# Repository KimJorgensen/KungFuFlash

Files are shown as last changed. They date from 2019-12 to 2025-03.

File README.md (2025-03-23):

# Kung Fu Flash

Cartridge for the Commodore 64 that packs a punch.

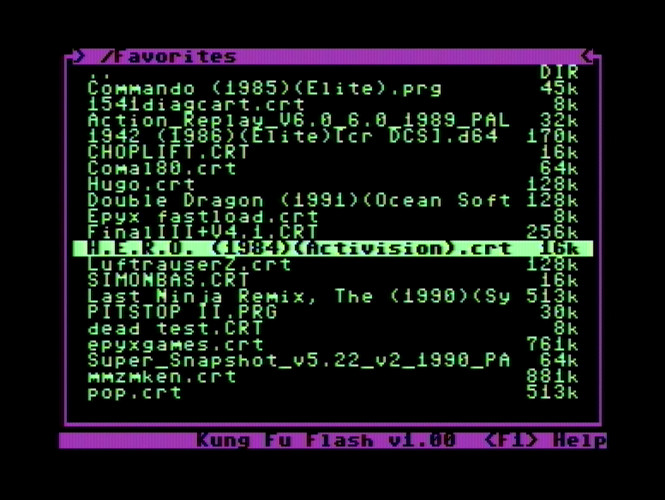
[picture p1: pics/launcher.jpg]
Kung Fu Flash Launcher


Kung Fu Flash can emulate different cartridge types, load PRG files and use D64 disk images.
Just place your desired CRT, PRG or D64 files on a FAT formatted microSD card and use the built-in launcher to execute them.

## Hardware

There are three buttons on the cartridge; a reset button, a menu button for starting the launcher, and a special button that is used by the freezer cartridges.

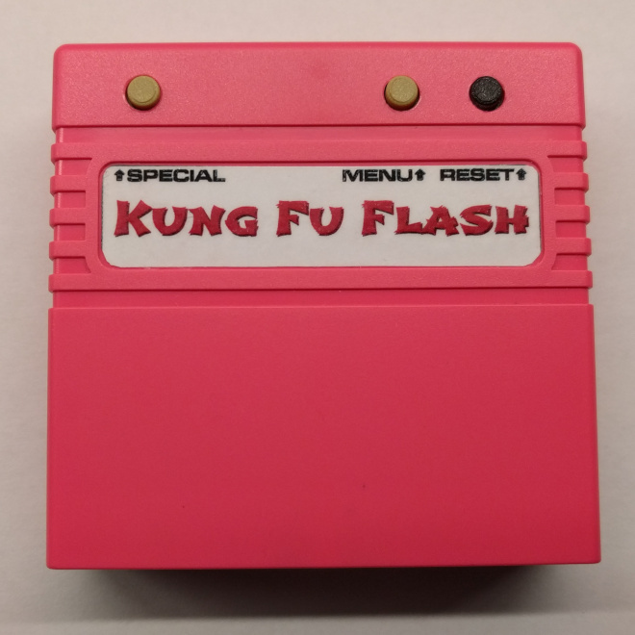
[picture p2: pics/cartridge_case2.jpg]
Cartridge Case


The PCB will fit the Stumpy Cartridge Case from TFW8b, you just need to drill some holes for the buttons and make a cut for the microSD card.
If you have mounted the USB connector you will need to cut a hole for that as well.

You can also 3D print a cartridge case as the one designed by bigby, [see here](https://www.thingiverse.com/thing:4153414).

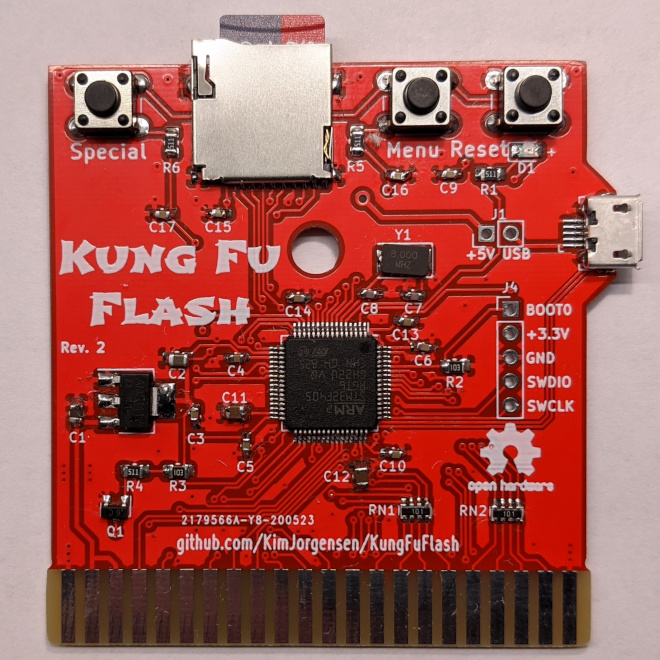
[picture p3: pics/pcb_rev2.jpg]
Kung Fu Flash PCB


The gerber files and BOM can be found [here](https://github.com/KimJorgensen/KungFuFlash/releases/tag/rev.2).

## Supported Cartridges

The following cartridge types are currently supported:

* Generic cartridge (8k, 16k, Ultimax)
* Action Replay v4.x/v5/v6
* KCS Power Cartridge
* Final Cartridge III(+)
* Simons' BASIC
* Fun Play, Power Play
* Super Games
* Ocean type 1
* Epyx Fastload
* C64 Game System, System 3
* WarpSpeed
* Dinamic
* Zaxxon, Super Zaxxon
* Magic Desk, Domark, HES Australia
* Super Snapshot v5
* Comal-80
* Ross
* EasyFlash
* Prophet64
* Freeze Frame
* Freeze Machine
* MACH 5
* Pagefox
* RGCD, Hucky
* Drean
* C128 Generic cartridge (external function ROM)
* WarpSpeed 128

## Supported File Types

The following file types are currently supported:

* Cartridge (CRT)
* C64/C128 generic cartridge (ROM, BIN)
* Disk image (D64, D71, D81)
* Tape image (T64)
* Program (PRG, P00)
* Firmware update (UPD)
* Text document (TXT, NFO, 1ST)

## USB Port

The USB port allows programs or disk images to be transferred from/to a PC using the EasyFlash 3 USB protocol.
The USB port is active when:

* The Kung Fu Flash launcher is running
* A program is started using "Load" in the file options menu (SHIFT+RETURN)
* BASIC is started via F7 in the launcher

Kung Fu Flash shows up as a standard serial port when connected to a PC not requiring any custom drivers to be installed.
This means, however, that the EasyFlash 3 program on the PC side must be modified to support Kung Fu Flash.
For that reason a modified version of [EasyFlash 3 USB Utilities](3rd_party/ef3utils) and [EasyFlash 3 BBS](3rd_party/ef3bbs) has been included in this repository.

## Firmware Update

Just place the KungFuFlash_v1.xx.upd file on the SD card and select the file in the launcher to initiate the firmware update.
The newest firmware can be found [here](https://github.com/KimJorgensen/KungFuFlash/releases/).

For initial firmware installation, [see here](firmware/README.md).

## Limitations

Kung Fu Flash is a so called Software Defined Cartridge where a fast microcontroller emulates cartridge hardware in software.
This makes it extremely flexible, allowing different cartridge types to be supported at a relative low cost.

However, it can be challenging to get the C64 bus timing correct in software and in some places the timing is very close to the limit.
Even though Kung Fu Flash has been tested on different models of the Commodore 64, there is a chance that it doesn't work correctly on your specific model, or requires [phi2 offset adjustment](firmware/README.md#diagnostic).
Use it at your own risk!

Kung Fu Flash will work with the PAL and NTSC version of the Commodore 64 or Commodore 128.

Disk drive emulation is using kernal vectors and will not work with fast loaders or software that uses direct hardware access which a lot of games does.
Currently REL files are not supported and only a subset of the Commodore DOS commands are supported.

## Thanks

Kung Fu Flash was based on or uses other open source projects:

* [EasyFlash 3](https://bitbucket.org/skoe/easyflash) by Thomas Giesel
* [Draco Browser](https://csdb.dk/release/?id=89910) by Sascha Bader
* [fatfs-stm32](https://github.com/colosimo/fatfs-stm32) by Aurelio Colosimo
* [FatFs](http://elm-chan.org/fsw/ff/00index_e.html) by ChaN
* [libusb_stm32](https://github.com/dmitrystu/libusb_stm32) by Dmitry Filimonchuk
* [stm32f4-bare-metal](https://github.com/fcayci/stm32f4-bare-metal) by Furkan Cayci
* [OpenC64Cart](https://github.com/SukkoPera/OpenC64Cart) by Giorgioggì
* [EasyFlash 3 USB Utilities](https://csdb.dk/release/?id=150097) by Tomaz Kac
* [Disk2easyflash](https://csdb.dk/release/?id=150323) by ALeX Kazik

and a few others. Please check the individual files for their license.

Thanks to Bjørn N. Jørgensen for giving this project its name.

Special thanks to the author of [Sidekick64](https://github.com/frntc/Sidekick64) Carsten Dachsbacher for his support and inspiration.

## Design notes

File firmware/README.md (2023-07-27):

# Kung Fu Flash Firmware
The initial firmware installation can be done via the SWD interface (J4) using a ST-Link V2 programmer or via the USB port.
The Kung Fu Flash cartridge should not be connected to the Commodore 64 before this process has been completed.

## SWD (Recommended)
Connect the ST-Link V2 programmer to J4 (3.3V, GND, SWDIO, and SWCLK) and connect BOOT0 to 3.3V.

Rename the `KungFuFlash_v1.xx.upd` file to `KungFuFlash_v1.xx.bin` and use the STM32 ST-LINK Utility from ST to program the firmware.

All wires to J4 should be disconnected once the firmware has been successfully installed.

## USB
Add a jumper to short J1 and a jumper to short BOOT0 and +3.3V on J4. This will power the board from USB and ensure that it is started in DFU mode.

Use the DfuSE software from ST or [dfu-util](http://dfu-util.sourceforge.net/) to install the firmware:

`dfu-util -a 0 -s 0x08000000 -D KungFuFlash_v1.xx.upd`

Both jumpers should be removed after the firmware has been installed.

## Diagnostic
Introduced in firmware v1.27

The diagnostic tool is started by pressing the menu button for 2 seconds (until the LED turns off) and is intended to debug stability problems on some C64 models.
For reference the phi2 clock frequency should be around 985248 Hz for PAL and around 1022727 Hz for NTSC.

As of firmware v1.44, the diagnostic tool allows adjusting a phi2 clock offset to address any stability issues.
Some C64 breadbin/longboards may require a small negative phi2 offset and C64C/shortboards may require a small positive offset.

In the diagnostic tool the following buttons on the cartridge can be used:

* `Special`: Decrease offset
* `Menu`: Increase offset
* `Special`, hold for 2 seconds: Save offset and exit
* `Menu`, hold for 2 seconds: Reset offset (without saving)
* `Special` + `Menu`, hold for 2 seconds: Reset and save offset. This combo will also work without starting the diagnostic tool first
* `Reset`: Exit diagnostic tool without saving offset

The phi2 offset is saved to the KungFuFlash.dat file and is reset if the file is not found on the SD card.

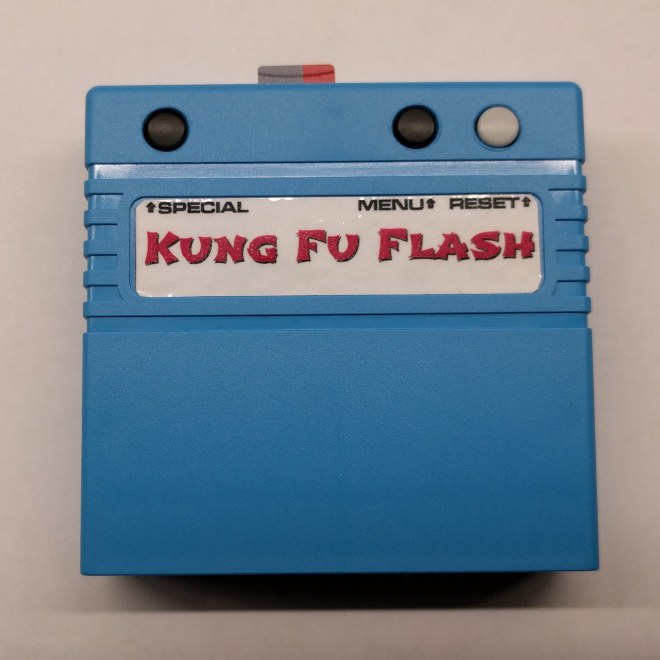
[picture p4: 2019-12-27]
pics/cartridge_case.jpg

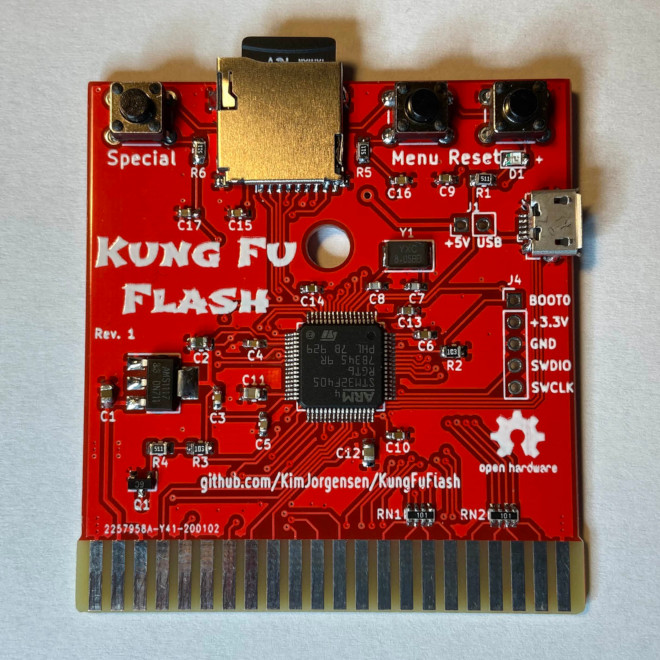
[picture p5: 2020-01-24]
pics/pcb_rev1.jpg

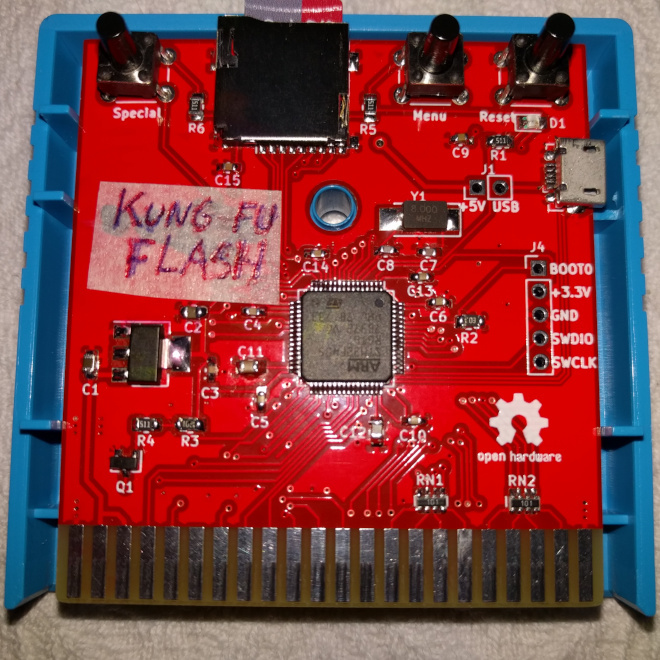
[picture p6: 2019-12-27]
pics/prototype.jpg

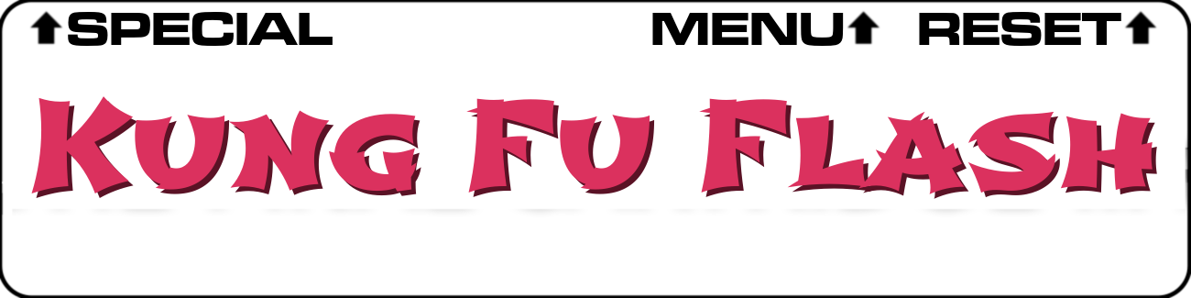
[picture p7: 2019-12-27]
pics/label_600dpi.png

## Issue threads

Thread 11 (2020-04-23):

BOM mistake

djtulan, 2020-04-23:
Hi!
In BOM there is a little mistake.

_Tactile Push Button Micro Switch - Use 6x6x6mm with TFW8b button caps or 6x6x9mm with 3.1mm A101 Plastic Switch Button Caps_

If somebody want to use the A101 Plastic Caps a 6x6mm with 10.5mm - 11mm height ist needed.

KimJorgensen, 2020-04-23:
Thank you for reporting this. That should be fixed.

djtulan, 2020-04-23:
The button height should be exactly 11mm. From the PCB to the top. I measured it again.

KimJorgensen, 2020-04-23:
Thanks. I'll update the BOM with this.

djtulan, 2020-04-23:
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

KimJorgensen, 2020-04-26:
The BOM file has now been updated with the correct size of the push buttons.
Thank you.

Closed 2020-04-26.

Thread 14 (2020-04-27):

Kernal support

dikdom, 2020-04-27:
Hello,
I was checked this cart (fantastic work, btw) and compared with EF3 and I realized that this one doesn't support the KERNAL switch, meaning that you could select a KERNAL image to replace the original one.
Is there any particular reason for that or just simply missed from the initial feature list?
Sorry for my ignorance I don't know how big deal is to implement that, so it may be a noob question..

KimJorgensen, 2020-04-27:
After being asked about this on forum64 I have looked a bit into it, but I think it is good to keep track of the issue here.
I have tried to implement the method described in "[Designing a Real KERNAL Cartridge](https://github.com/KimJorgensen/easyflash/releases/download/EF3-FC3/kernal-cartridge.pdf)" by @skoe but has not been successful so far. Pulling A14 low from KFF does not seem to work, maybe the timing is off or maybe the signal isn’t pulled low enough.
More investigation is needed.

dikdom, 2020-04-27:
Thanks for your reply and thanks for sharing a the doc, I haven't seen it earlier!

In the KFF there is only a 8MHz clock (oh, OK, you may have PLL), on the other hand I don't understand why it doesn't cause any conflict (HW failure in time) to pull down A14 externally while the CPU may drive it to high..
And yes, the doc doesn't mention how does the EF3 pull down the A14 safely (below 0.8V I guess) without burning the CPU.

Thanks for your time!

KimJorgensen, 2020-04-27:
The ARM processor runs at 168MHz but there are delays involved reading the bus, checking for the correct condition, writing back to the bus etc. It will almost always be slower than when implemented in hardware or a CPLD as EF3.
If you check the schematic for EF3 there is no hardware protection on A14. The signal goes straight to the CPLD which can sink up to 70mA if I read the datasheet correctly.
I think the key to not damage the CPU is that A14 is only pulled down a fraction of the clock cycle and this is only done after a write to address $0000 or $0001.

skoe, 2020-04-27:
@KimJorgensen This is correct. These are the points that allow this to be done:

- NMOS pull-ups are quite weak. They can't source much. However, the closer the output comes to 0V, the stronger they get.
- It's a fraction of a clock cycle only, as you said.
- It happens at most every few clock cycles, usually much much more seldom. So the FETs can't heat up.
- Actually, similar effects happen in every machine: When the chip select changes from one IC to another, not all of them have the same speed, so the data bus may be driven from one IC already before the previous IC lets it go.

About the timing: It must be really very accurate I remember. It was many years ago, details I can't remember unfortunately.

Hope this clarifies your question. Note that I didn't have a look at this project but got a notification from github :)

dikdom, 2020-04-28:
Hello,
checking the STM32f405RG spec I read a note (DocID022152 Rev 8, page 59):
"PC13, PC14, PC15 and PI8 are supplied through the power switch. Since the switch only sinks a limited amount of current
(3 mA), the use of GPIOs PC13 to PC15 and PI8 in output mode is limited:
- The speed should not exceed 2 MHz with a maximum load of 30 pF.
- These I/Os must not be used as a current source (e.g. to drive an LED)."

1) Can it be the cause that you cannot change at proper speed the /GAME and /EXROM lines (max 2MHz seems not enough if you need to pull them down for 80ns or 160ns)
2) PC13 is a current sink, so driving a LED is not a problem here, I guess.
3) I have one more question thought it seems trivial (but not for me, sorry). How do you know that the ARM chip is 5V tolerant?

KimJorgensen, 2020-04-28:
@skoe Thank you for taking the time for the clarifications and for your excellent document. If you can find the time, please consider putting the newest version on your website so others can find it too. From what you are saying I assume that the timing is off but I really need to verify that with a logic analyzer.

@dikdom
1. That could be. I haven't really spend any time investigating this
2. Yes, using it as a sink works fine. I'm not sure that is documented anywhere
3. In table 7 in the document that you referenced there is a "FT" next to each pin that is 5V tolerant

It was actually quite a puzzle to map all signals to pins, as they all are in use. Not all are 5V tolerant, some have a different use when running the bootloader which could damage the C64, and not least, it should easy for the software to read the address and data bus without having to do bit shifting.

dikdom, 2020-04-28:
3. I just should have read 2 more lines... :) The note I sent earlier is in the same legend of the table 7 you are referring to..
I can deeply understand the puzzling part. I'm not an expert, designing a PCB for me is let the autorouter do the job (under a few MHz there should not be too much harm)..

So in this case I'll probably wait sometime with the ordering the PCB and I hope you will come up with a good solution... :)
I would multiplex the /EXROM and /GAME with the SD reader pins (you don't use the SD and the C64 at the same time, I assume) and disconnect the C64 lines with a 4066 like switch when using the SD.
But the SD lines are the other side of the MCU and of course I don't know if the multiplexing could be done at all, and the bit-banging... and.. a lot more can be considered I don't even think about.

medzes, 2021-02-01:
HI all,

I've successfully been able to get kernal mode working exactly as skoe documented in his excellent article in KungFuFlash, using the DEVEBOX prototype I have. The tricks needed to do that are primarily a lot of work getting the timing right and checking the oscilloscope.
Now I don't own a regular KungFuFlash cartridge so I cannot test / check the timing for the regular cartridge and I can also not check the slope speeds of the signals for the regular PCB rev2 version. I have PA14, EXROM, GAME on a regular GPIO. (not on PC13,14,15). But I expect the same tricks below would work on PCB rev2 as well.

What was needed to get it to work:
- Normal 5V tolerant use for EXROM, GAME means open-drain config. However, this means both EXROM and GAME have a rising edge slope that is far too slow to reach the timing mentioned in skoe's document during the A14 tests.
- It is also likely in some corner cases like some C64 PCBs or some specific address transitions causing voltage drops, the half-cycle delay between releasing GAME and the begin of next CPU cycle may not allow GAME to be pulled up fast enough by the resistor inside the C64 alone.
-  So, a trick is needed to momentarily set EXROM/GAME to normal high output with a 4 cycle wait (in my tests) to let EXROM/GAME reach 3.3V, before releasing them to let the pullup resistor in the C64 handle the rest.
- We cannot leave EXROM/GAME in output mode all the time as that would mean the C64 pullup resistor for EXROM/GAME will increase the 3V3 on the ARM IC. This may lead (if the arm is not consuming enough power) to a 3V3 above 3.6V, which damages the ARM.
(I have however programmed EXROM/GAME to output fixed by mistake though, and that didn't blow up anything - then again the 2 LEDs on the DEVEBOX alone draw a few mA alone, probably sufficient to keep the 3V3 below 3.6V)
- A14 is pulled low very fast after it is set to output, and rises back high very quick too after release. No special stuff needed.
- The A14 check loop requires more time before the interrupt occurs than the existing cartridge timing allows. I've re-implemented a specific handler from scratch with earlier interrupt timing to fit the tighter timing.
- The A14, EXROM, GAME OTYPER/MODER toggling are highly dependant on exact cycle delay inbetween the actions. Using NOPs didnt allow sufficient time for all functions so I had to move some logic around As a result, the code is C but it is so sensitive to the compiler / optimizer and exact constants, it might as well be assembly.
- The 48kB code size is very full, so I switched to -Os and some always_inlines. This allows the kernal code to fit.

I will upload my changes to my fork after I have been able to run some tests that perform $00 / $01 tests. Does anyone have some suggestions what C64 software to use (that changes $00/$01 a lot and is very sensitive) to test the functionality properly?

skoe, 2021-02-01:
Congratulations :) Regarding the tests: I tested the mechanism with hand written assembly loops, because this made it easy to check everything on a logic analyzer. And when this worked, I run all kinds of programs :)

Did you also implement the mechanism from chapter 2.2 Optimizations to avoid pulling down A14 in every cycle? The will reduce the stress on the bus drivers significantly.

medzes, 2021-02-01:
Hi skoe,

Thanks for that insight. I guess I could also write and use some handcrafted loops, will take some time to integrate that.

Yes, I have also implemented the mechanism to avoid pulling down A14 every cycle as you suggested. In fact there are 3 separate interrupt service routines, currently using a state variable. It could be optimized using 3 separate ISR vectors, that would make the A14-check ISR with its tough timing more compatible with background usb or other activity by switching to the less restrictive timing (without the A14 check) on the fly.

I notice in the idle kernal loop, there are occasional $01 writes happening at some kHz rate. So from this I believe its all working correct. The interrupt timing of the arm is fortunately very exact so far. I may need to support a 1 or 2 cycle ISR delay inaccuracy - I use a C64 VIC cycle alignment style loop to get to 1 cycle accurate timing based on the Timer capture value. That part was very fun - almost exactly like using the 6526 timer to get in lockstep with the VIC, but then on the ARM with phi2.

medzes, 2021-02-11:
Hi, I've been able to find the time to clean up my code,  test it a bit and make it ready for others to check out. You can find the kernal mode on my fork. It can be compiled for PCB rev 2 or DEVEBOX using a define in the Makefile.
This version is not yet rock steady, but it does work for many code and games.
The code supports two mode:
- Select a kernal ROM file. Drops you into a normal basic screen.
- Place a file called "kernal.bin" on your SDcard. If this file is detected, it will be used to start PRG and disk based programs from the easyflash menu.
Please note I have not checked the PCB rev 2 version as I don't own one.
If you are interested to test, please be aware the constants of peripheral base addresses are different which can make the compiler create code with slightly or even big timing differences. It is best to compare the generated kernal_handler code in the build/main.lst by hand in case of doubts.
Also it is a good idea to check with an oscilloscope the timing of the A14 check and the $de02 write check. The kernal.c file contains some notes how you can do that and what timing to expect.

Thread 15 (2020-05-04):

BOM question

dikdom, 2020-05-04:
Hello,
could you please put a photograph about the cart from the USB socket side as I'm having a hard time figuring out what kind of USB socket is needed (tbh I'm afraid of ordering from Ali because of the arrival time of the free shipped orders...). So. On the kicad PCB file it seems that the bottom pin is the pin 1, +5V from USB, top pin is GND, pin 5. So, checking the pinout of the microUSB socket from the wiki (https://en.wikipedia.org/wiki/USB_hardware), the socket has to be laid on its longer side (shorter side of the microUSB trapeze is UP). But checking the picture on the ali link you specified in the BOM, it is quite the opposite. So which one?
I assume you already used the USB interface of KFF, so it works that way you have in your cart.
A picture would help me a lot.
Thanks!

KimJorgensen, 2020-05-04:
Hi,
The bottom pin is pin 1 and the socket is laid on its short side, just like shown on the wiki (https://en.wikipedia.org/wiki/File:USB_Micro-B_receptacle.svg).

Here is a picture:
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
And yes, the USB interface works fine.

Hope this helps and please let me know if you find a suitable replacement.

dikdom, 2020-05-04:
Thanks, then I mixed the front and back view... This picture is not so straightforward.. https://en.wikipedia.org/wiki/USB_hardware#/media/File:USB_2.0_connectors.svg
I'm glad I asked! :)

For the micro USB B socket I hope this will work for me: 10118194-0001LF from Amphenol.
For the micro SD card socket I'm targeting this: 112J-TDAR-R01 from Attend.

Some months and I will let you know the results! :)

Closed 2020-05-04.

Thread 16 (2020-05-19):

troubleshooting

dikdom, 2020-05-19:
Hello,
a little help would be appreciated...

So, PCBs arrived, most of the parts are pre-soldered. USB and SD slots, switches and jumper headers had to be soldered by me - done. Checked the USB slot with a cut USB cable, each wire is OK (+5V, GND, D- and D+, no shorts)

- firmware (v1.08) is uploaded ('Downloaded' in the terminology of dfu-utils) and read back ('Uploaded') and verified. It is OK.

Q1: is it true that the computer should be able to see the board if I press all the three buttons at the same time? I have to press them at once in order win10 be able to see it.

Q2: no LED activity, when the board is connected to USB. Is it normal?

- OK, fw programmed, when I try it with C64, the LED is lit but the screen remains black. With an SD card, without an SD card.

I tested the SD slot's pins and they aren't shorted.

Q3: Any idea where to start the debugging?

UPDATE#1:
A3: RN1 and RN2 is 10k resistor networks. Needs to be replaced, to be continued...

KimJorgensen, 2020-05-21:
Hi,

Q1: There is no functionality that requires you to press all buttons at once. It may be necessary to press the reset button after shorting BOOT0 and +3.3V to make the microcontroller enter the built-in bootloader. When the bootloader is running the device should be detected by windows.

Q2: Yes, there is no LED activity when the bootloader is running.

Q3: If replacing the resistor networks doesn't help then try it with a different C64, preferably one with an original kernal and PLA.

dikdom, 2020-05-21:
Thanks!

rickard-von-essen, 2020-08-11:
@dikdom was this resolved by replacing RN1/RN2?

dikdom, 2020-09-07:
@rickard-von-essen yes, it did the trick.

Closed 2020-05-21.

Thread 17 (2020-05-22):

Questions

dikdom, 2020-05-22:
Hello,
finally I managed to fix my cart and it starts, it works. Most of the things are abvious and fine but I have some questions:
1) when I turn on the cart or reset sometimes it starts with the normal C64 boot screen and sometimes it goes directly to the KFF menu. What does it depends on?
2) I have found the F5 configuration option. What does that exactly mean? Is there any longer description about it somewhere?
3) Final Cart III and FC III+, the freeze menu is strange, though it works. There is some flash on the upper menu and on the drop down menu, but it is responsive to the keys and works. I will attach a screenshot later (motherboard 250407, normal PLA chip). With a FCIII+ cart and with an original FC cart there is no problem on the freeze menu on this machine.
4) What driver shall I install onto windows 10 in order ef3util.exe to work? The driver from the EF3 site cannot be installed as it is not signed.
5) What happens if I happen to turn off the machine while it is loading (flashing?) one of the .crt images - when I select those? Will the KFF be bricked? Or just the Action Replay will not start? Or?

Thanks a lot,
Sandor

dikdom, 2020-05-22:
Let's skip 3) as I have a slightly broken SID chip in this machine. With a different, c64c machine there is no problem with this cart. I have to check different SID also...

KimJorgensen, 2020-05-22:
Hi,
Good to hear that you got it working.

1. That depends on your last selection. Say you select BASIC (F7) then the cartridge starts in BASIC after reset or power on. If you don't wan't the cartridge to "remember" your BASIC selection this can be changed in the settings menu (F5)
2. Sorry, there isn't any longer description. Hopefully it is understandable what is does with my answer to your first question.
3. There are timing differences between different C64 machines and as the timing is close to the limit there is a chance that you encounter a machine where the cartridge doesn't work correctly. If you have the possibility to replace the SID chip let me know if the problem persists.
4. It shouldn't be necessary to install a driver as KFF is added as a COM port but you need the ef3usb.exe from the KungFuFlash GitHub page.
5. There is a slim chance that it will be bricked, but most likely the flash will be corrupted and KFF will start the menu next time it is powered on.

/Kim

dikdom, 2020-05-22:
Thanks!
1) so if I set the config in F5 to 'no' then it will always powers on onto the menu . If I set the config to 'yes' it will powers on into BASIC. The
resets will always takes you to the last selection (prg load, mount, etc..) regardless of the config. Did I get it right?
3) sure I will
4) hm.. I'm using the .exe from your github, so probably yes, it was ef3usb.exe . How long should it take to transfer one .prg file? Minutes? After 30s-60s I stopped the process as it seemed it crashed. Same with the testing. It prints it started but then nothing...

KimJorgensen, 2020-05-23:
1. No. Power up and reset works the same way.
In the default configuration KFF will always take you to the last selection which includes BASIC. If you set the config to 'no' then the BASIC selection wont get saved and KFF will go to whatever you selected prior to BASIC.
4. The transfer should only take a few seconds. What command exactly did you run, and did you make sure to specify the correct COM port?

dikdom, 2020-05-23:
point 1)
now I understand. KFF will always boots up to the latest selected action, the config only selects if these actions would include the BASIC screen or not. Ok, I was completely off the track with this.

point 3)
The working SID didn't solve the problem. In fact, when I started the freezer menu of FCIII on another 250407 board, then the menu line was also corrupt, but not that much, only within one raster line. Starting the KFF in a 425 board, then the freezer menu was OK. I have tested KFF on a 469 also, and there were no problems either.

point 4)
I executed 'mode' command to check the usable COM port. It was COM6 in my case. If I remember correctly it was 'ef3usb.exe com6 test' and 'ef3usb com6 c xy.prg' or something like that. The menu screen changed on the C64 screen, so something had happened, but not quite what I expected..
I will try different C64 machines.

Good news is that I managed to test with the PLA20V8 PLA replacement and it works with it as with the original PLA.

KimJorgensen, 2020-05-23:
3) Thank you for testing this. I'll try to see if I can fix that once I got my 250407 board working, but it is quite tricky to get the timing right so that it works across all board revisions.
4) Just like EF3 you must send the ef3usb.prg program to the C64 first before you can use the test or copy command. So try to execute `ef3usb com6 s` first

Thank you for the info about the PLA. I'll update issue #12 with this.

dikdom, 2020-05-23:
4 - ef3usb.exe works as you described. I don't have an EF3 so I was not familiar with the procedure. And I stopped reading the doc at: 'PC has installed Easyflash 3 USB driver.' (quite the beginning of the readme.txt)
A small disappointment that this utility is not for transferring data to SD card, and quite a pleasant surprise that it is possible to transfer image/files onto real 1541 floppy disks.
Thanks for your support!

KimJorgensen, 2020-05-24:
Yes, the readme file should be updated.
The only change that was made to EasyFlash 3 USB Utilities was the how it communicates with the cartridge. No features were added to read or write to the SD card.

I don't think I would extend this utility with these features but rather have it build into the Launcher (see #13)

dikdom, 2020-05-24:
Ok, thanks!

Closed 2020-05-24.

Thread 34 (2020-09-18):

DFU Mode

Icelvlan88, 2020-09-18:
Hello,

I cannot get my unit to go into DFU mode. I checked all my connections and I just can't get it to go. I shorted J1 and BOOT0 to 3.3v.

I also checked continuity between my usb pins and the processor. I'm not getting any voltage. I also tried using a different USB cable and no go. I tried both applications you suggested swell.

Can you give me any ideas on what I should be trying? Is there something that is supposed to be sitting between the usb cable and the PC? Using windows.

C-64Bram, 2020-09-18:
I had the same problem. After rebooting my pc the card became visible in DFU mode. It the device is removed and reconnected ,  it sometimes becomes visible again and sometimes I have to reboot again.

jgilcas, 2020-09-18:
Same issue here, i bought a stvlink programmer and everything works perfectly, for 2e i dont expend time to solder jumpers pins

C-64Bram, 2020-09-18:
Like this?

https://www.st.com/en/development-tools/st-link-v2.html

Op vr 18 sep. 2020 13:09 schreef jgilcas <notifications@github.com>:

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

jgilcas, 2020-09-18:
This one: https://es.aliexpress.com/item/32719963657.html?spm=a2g0s.9042311.0.0.274263c07ACJ8a

C-64Bram, 2020-09-18:
Nice. :-)
Just ordered one. :-)

Op vr 18 sep. 2020 14:45 schreef jgilcas <notifications@github.com>:

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

Icelvlan88, 2020-09-18:
I ordered one from a different vendor and receive a STC Auto Programmer USB-TTL. Will this function? Pins looks to have different names

On Sep 18, 2020, at 8:49 AM, C-64Bram <notifications@github.com> wrote:

Nice. :-)
Just ordered one. :-)

Op vr 18 sep. 2020 14:45 schreef jgilcas <notifications@github.com>:

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

—
You are receiving this because you authored the thread.
Reply to this email directly, view it on GitHub<https://github.com/KimJorgensen/KungFuFlash/issues/34#issuecomment-694847699>, or unsubscribe<https://github.com/notifications/unsubscribe-auth/APCADXLSNNZLJFJTI52WDWTSGNJOLANCNFSM4RRNSAHQ>.

dikdom, 2020-09-24:
Hello,
check, if you have 5V between the J1 pin header (if it is shorted then any of its pins) and ground (shield of USB). If you have 5V check the voltage regulator whether you have the 3.3V at its output. If you have it, you should check the MCU also to have the 3.3V . Make sure the two pins of J1 and 3.3V and BOOT0 pins on J4 are shorted.
After connected everything, press the reset button of the card, it helped to be identifiable by my PC.
I used dfu-utils and the latest .upd binary to flash my card. It worked for me.

Closed 2024-12-29.

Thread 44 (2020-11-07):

STM32 Program

Icelvlan88, 2020-11-07:
Hello,

I'm trying to program the STM32 and I keep getting an error. "Connect Under Reset" mode Target -> Settings menu and try again.

I tried programming another STM32 and was able to, so I know my usb is working correctly.

Can you tell me which pins should be connected directly to Boot0, 3.3V, GND, SWDIO, SWCLK and ill try to connect directly to the processor?

I have pin 1 on the STM32 facing C13, so I know the orientation is correct.

I also tried to reflow the board with no luck.

Also, if D1 is not on the board will it still function to program?

KimJorgensen, 2020-11-07:
Hi

Are you using a ST-Link v2? If you got the microcontroller from China there is a chance that the read out protection is enabled. In that case you need a ST-Link v2 and the ST-Link Utility from ST to unlock it.

The schematic for Kung Fu Flash can be found [here](https://github.com/KimJorgensen/KungFuFlash/blob/master/hardware/KungFuFlash.pdf) but it shouldn't make any difference if you connect the pins directly to the microcontroller. D1 is not needed for programming the board.

Icelvlan88, 2020-11-07:
Hello,

I got a ST-Link v2 and the microcontroller is not from China. What is the process to unlock incase? I checked all my continuity and everything looks fine. It says Detection fail on the STM32 settings in the ST-Link utility.

Can you confirm pin 1 on the STM is the corner where C13 is located?

KimJorgensen, 2020-11-07:
The ST-Link Utility will detect if the read out protection is enabled when you try to program the microcontroller and give you the option to unlock.
The microcontroller needs 3.3V which it should get from the ST-Link v2 and the BOOT0 pin should be connected to 3.3V. I guess you have done that, so I would recommend checking the solder joints on the microcontroller with a microscope if you haven't already.

Yes, pin 1 is in the corner where C13 is located. You can see the orientation of the microcontroller [here](https://github.com/KimJorgensen/KungFuFlash/blob/master/pics/pcb_rev1.jpg)

Icelvlan88, 2020-11-07:
For the programming portion, does any other pin need and or 3.3v?

KimJorgensen, 2020-11-07:
You only need to connect 3.3V to to the J4 pins labeled "+3.3V" and "BOOT0".

Icelvlan88, 2020-11-12:
I soldered 3.3V and BOOT0 together. Might have a bad chip. Ordered a new one.

Icelvlan88, 2020-12-13:
Was able to program, but I have an NTSC C64. Any idea when you'll be able to add support? Is it a software or hardware thing? When the cart is inserted, the system won't turn on.

KimJorgensen, 2020-12-14:
NTSC support is a software issue that is being worked on. There is already an issue for this (see #6) so I'll close this one.

Closed 2020-12-14.

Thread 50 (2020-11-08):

D64 with loading in game not working

Outrun69, 2020-11-08:
When I load a game in which there are other loads, such as the title screen and then the following levels, it does not work.  In-game loading does not work.
Another exemple : I load koala painter and when I want to load picture there is an error message : device not present.

mrr19121970, 2021-01-21:
Is it possible to respond to the mw and me commands the same as an sd2iec ? For example in fload https://csdb.dk/release/?id=114912 if the response is the same as sd2iec then the fast load is disabled and kernel routines are used instead

medzes, 2021-05-01:
Hi, I think this could be reconsidered.

I've done some analysis on the delta between the set of working SD2IEC images and the working KungFuFlash D64/ D81 images.

Surprisingly only few of the SD2IEC D64/D81 images seem to use a fastloader. Most of them use a regular kernal fallback.

I estimate on top of the current working KungFuFlash set, around 400-800 existing SD2IEC D64/D81 images could work out of the box if the CBM-DOS command set is extended to a more complete set.
I checked using Vice's +virtualdevice mode. In that mode, a virtual drive is connected where most CBM-DOS commands work but all the memory-read, memory-write and memory/block execute commands generate a "Syntax Error".
Supporting (most) of the virtualdevice CBM-DOS commands seems to be enough to make the fastloaders in the SD2IEC set disable themselves, and supporting the track/sector loading/saving (U1/U2) as well as opening files with CBM-DOS extended naming like "0:A4,S,R" seems to be sufficient, use character-by-character mode for both read and write.

Supporting these D64 images, does require some refactoring of the current D64 support code on both C64 and ARM, then after that refactoring some implementation of the basic CBM-DOS command set.

- One more Kernal call (CHROUT) needs to be trampolined. This might be done if the filename buffer at $df00 currently is removed and replaced with character-by-character calls.
- Parsing commands on channel 15, and extended filename support on other channels.
- The Open and Close could be done using only Talk/Untalk Listen/Unlisten like the actual device does
- Supporting the 15 buffers fully
- REL file support (although I don't expect that to be used much in the SD2IEC set)

Most of this is quite doable, but I do wonder if the added ARM code would still fit in the available space. I expect the ARM code would take > 8 kB of space at least.

findrepo, 2022-04-05:
Dear contributors,

I just started using this cartridge recently and I mostly use D64 files, but with mutliple disk games.

It is an issue even for PC/Android etc emulators that when I select an other disk it interrupts the current running code or resets and executes/types in the LOAD command etc.

All I want is just to be able to mount a different D64 image without interrupting the current game when it asked me to change the disk in the drive.

I think with the current implementation here, I have to push menu button which makes a RESET and runs code from FW and I can mount other disk, but the running game already wiped out...

There could be an easy solution for it I assume:

- selecting a D64 would set the file path/name in a variable of the MCU, so just some local variable not in the C64 loader program like "idoregesz_disk1.d64"
- when pushing the "special button" the MCU could increase a counter like "idoregesz_disk2.d64" in the file name and mount the disk with the incremented name and call the routine on drive as tray open and closed/ejected disk and inserted (if possible)
- game would not be interrupted as everything happens in the MCU level...

I know it won't be a perfect implementation as need to put images in a sequence but could be a workaround for change the disk ingame issue.

What do you think?

If possible I can also help in the implementation and fork and try to implement is, just might need some advices where to start as I have limited time developing hobby stuff :(
I worked in STM32 based projects, mostly on drone firmware modifications previously.

CqaZ80, 2022-08-01:
> Is it possible to respond to the mw and me commands the same as an sd2iec ? For example in fload https://csdb.dk/release/?id=114912 if the response is the same as sd2iec then the fast load is disabled and kernel routines are used instead

I think KIM did not see this message, maybe he missed it, you could publish it as a new topic.  I think your proposal is very good!!!  that would improve compatibility a lot!!!  and many D64 images that don't work today could eventually work.

Closed 2024-12-29.

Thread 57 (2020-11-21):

KFF rev 2 pcb black screen issue

tdididit, 2020-11-21:
Hi,

I have a black screen issue.
I've been trying two firmwares 1.09 & 1.14 with same result on 2 assembled boards

Firmware flashed with ST-LINK v2.
Device is entering into DFU mode too, without BOOT0 jumper windows is detecting it as a Kung Fu Flash.
Because i have in one of my C64 swinSID (it beeps on reset) I know that system is resetting after RESET & MENU button press.
LED on KFF is lid

tdididit, 2020-11-21:
SOLVED

I replaced Q1 transistor with 2SC945 and it works now :)

Closed 2020-11-21.

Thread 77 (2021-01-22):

New PCB revision for backwards pointing buttons ?

UffeJakobsen, 2021-01-22:
First KFF is becoming a really nice project :-)

I've on several occasions experienced that pressing the cartridge buttons tend to "wriggle" the cartridge in a way that the system crashes (freezes).

A qualified guess is that the "wriggle" happens due to the upward pointing location of the buttons.
If the buttons were backwards pointing this would not happen.

This is observed from time to time with two KFF carts in four different systems - and I must admit that it is annoying that the user has to be careful about how he/she presses the buttons and/or need to support the cartridge with standoffs on the backside.

I know that the backwards pointing buttons has another mounting-layout - so my suggestion would be to incorporate this into any planed revision of the PCB.

KimJorgensen, 2021-01-25:
I have experienced the same thing on one of my boards but cleaning the connector did resolve the problem. So I'm wondering how many has this problem and if cleaning the connector would also help them?

uffejakobsen, 2021-01-25:
> I have experienced the same thing on one of my boards but cleaning the connector did resolve the problem.
> So I'm wondering how many has this problem and if cleaning the connector would also help them?

Well, I have tried that also - but I still see crashes caused by pressing the buttins from time to time...
I guess that our C64's are just getting old (they are) and the expansion port have been in used and worn for over 35 years.
Most other cartridges have backwards pointing buttons - and they do not give me the same trouble when used with the same boards

rickard-von-essen, 2021-01-25:
A device like this is helpful:

https://www.ebay.com/itm/Tombstone-64-Commodore-64-reset-board-and-expansion-port-angle-adapter-combo-/283816694848

uffejakobsen, 2021-01-25:
> A device like this is helpful:
>
> https://www.ebay.com/itm/Tombstone-64-Commodore-64-reset-board-and-expansion-port-angle-adapter-combo-/283816694848

Thanks - but I already own several C64 expansion port extenders :-)

That will only move the problem - you are still pressing the buttons in the wrong direction

Also using an expansion port extender in order to fix this issue seems a little weird...
And it won't certainly help to the success of this device - if a subset of the users will have to apply such "patches" to KFF in order to get stable operation - that should come from the device itself.

pmandes, 2021-03-20:
Hi,
I cloned the main repo and made a separate branch with a new PCB that has right angle tactile switches:

https://github.com/pmandes/KungFuFlash/tree/long-board-cart

...still a work in progress, but I'm almost at the finish :)

kroesi, 2022-02-12:
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

Hello @pmandes,
thank you for creating this fork. Did you build it? Does it work?
I just wanted to order it at jlcpcb with assembly, but the STM32 was to expensive for me at the moment without knowing if it will work.
Krösi

pmandes, 2022-02-12:
Yes I built it, tested it and it works very well, however I didn't make the SMT assembly files so you have to either assemble yourself or generate these files yourself with KiCad.

Closed 2025-03-08.

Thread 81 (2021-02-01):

Unstable sdcard reads

medzes, 2021-02-01:
Hi all,

I have a situation that my sd-card is frequently (25% of the time) mis-read and gives read errors at random times, like when loading the next page of directory entries. Anyone have an idea if there is some timing related issue or some STM32-configuration related setting in the code I could try to change to see if that helps?

KimJorgensen, 2021-02-02:
Based on what you have written elsewhere I'm assuming that you not are seeing these issues with the Kung Fu Flash firmware but are using some derived firmware that you developed.

If you have changed the firmware in such way that you are spending more time on interrupts then you could get timeouts or buffer overruns when reading or especially writing data to the SD card. You could try enabling error logging in diskio.c

medzes, 2021-02-24:
I have finally been able to spend time tracking down the reason for the sdcard issues I was having. Fortunately I've been able to solve them and make KFF work rock solid.

I enable the hardware flow control bit in the SDIO peripheral's control register. After this, I have not had trouble with buffer underruns anymore.
I also implemented support for the 1/4 fifo full bit in the  SDIO->STA status register. When that is high an do 8 fifo reads at once without checking status again.
I also added some __DMB()'s after SDIO register writes, to help lower interrupt lacency.

My main guess why I'm having more issues, where all I changed in KFF is the GPIO ports used, is that the compiler version just happens to have small difference that can have nasty side effects on interrupt latency jitter. Minute code changes to the interrupt routine can cause the C optimizer to take a slightly different path, with a (comparitivly) huge delta in interrupt routine delay. (like needing one more register on stack, or no stack at all, or having a constant as a LDR or as a MOV)

It turns out after measuring that the worst case C64 interrupt delays all happen during a read of the SDIO->STA register. Reading this register takes 7 or 8 cycles (not documented anywhere but I measured this with the debug cycle counter).
But the jitter I measured in the interrupt can be more than just those 7 cycles, if the ARM's write-buffer is still not empty. So the worst-case latency that came up in my measurement, was the SDIO register write (takes around 6 cycles) followed by branch to a load of the SDIO->STA register (7 cycles). Total latency around 15 extra cycles on top of the minimum 12.

It seems due to the non-empty write buffer, but the LDR already being in the pipeline of the ARM, the whole chain cannot be aborted to handle the interrupt any earlier.

@Kim would you be interested in a pull request for the sdio fixes I made?

KimJorgensen, 2021-02-25:
Thank you for your detailed description.

No offense, but to avoid confusion and respect the license, I would appreciate if you distinguishes between Kung Fu Flash and your derived work. As far as I know, Kung Fu Flash does not have any stability problems when accessing the SD card.

It was a conscious decision not to enable SDIO HW flow control due to the problem described in the [errata sheet](https://www.st.com/resource/en/errata_sheet/dm00037591-stm32f405407xx-and-stm32f415417xx-device-limitations-stmicroelectronics.pdf), see section 2.13.1.

I would be a bit reluctant to accept a pull request that fixes a non-problem, especially with the above in mind, but thank you for the offer.

medzes, 2021-02-25:
Ah thanks, I had not seen that errata sheet. In that case the hardware flow control should be left disabled. The 1/4 fifo trick still helps sufficiently for my code.

Agreed, if the SDIO issues are a unique result of the set of pin assignments I am using and possibly different gcc version (I use the one from ubuntu 20) that is fairly strange but no need to merge.

No offence, but I am not sure how to work along with your request on license. I don't think I have sufficient understanding of legal issues to understand the request you have.

I would not expect the changes I made that I have published so far to be allowed to be called a different project. The only substantial change is in one file (c64_interface.c) to allow two optional choices of GPIO pin assignments during compilation and other minor changes to allow -Os compilation. I've personally only seen this as minor software changes to allow support for a "hardware prototype" version of KungFuFlash.

It appears you have far more experience with that than I have, would you care to offer a suggestion how to proceed?

The other changes so far are adding soft-kernal support, optional LCD, and optional side-load of ARM code. Those features use some additional files which I have used the same copyright as yours, but with my name as author. I suppose including those in a compiled binary could be called a derived work, indeed. Would you be happy if I called that KungFuFlash-devebox, to clarifify it works on the devebox prototype ?

KimJorgensen, 2021-02-26:
As long as it is clear that your work is not the original Kung Fu Flash I'm happy.
I'll close this issue and thank you for the info.

Closed 2021-02-26.

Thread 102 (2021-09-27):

Unstable clock values with Diagnostic feature on 1.27

lordoftears, 2021-09-27:
My KungFuFlash works with every C64 I have, but I have a curious issue with my Sixty Clone (assy 250466): often (3 on 5 attempts), when I press the Menu button, I have garbage on screen. Then I press it again and everything is fine. Games are loaded fine and I can enjoy the cart.

I performed the Diagnostic due to the new 1.27 firmware. With the Sixty Clone the clock is moving from 887450 to 987750, while it is ok (fixed value) on a breadbin C64 I tested.
I have no other issues with the Sixty Clone, which is usually connected to a Ultimate 2+ device and has a good video on my 1084s monitor.

KimJorgensen, 2021-09-27:
Is the clock always unstable when you enter the diagnostic? and does it get stable after running the diagnostic for a while?

What chips have you used to assemble the Sixty Clone board? Are they all original Commodore, or has some replacement chips been used?

lordoftears, 2021-09-27:
The clock is always unstable. At each cycle, it changes, I waited for several cycles but it continues moving. It looks strange because with that oscillation the video output should be bad, instead it is good.

The Sixty Clone has original chips except for the PLA and an ARMSID.
Some months ago, when I experienced the issue with the menu button, I tried swapping the chips with a different C64, which mounts original chips, but nothing changed.

KimJorgensen, 2021-09-27:
Yes, I would also expect the video output to be affected if the frequency did change that much. Maybe it is a bad connection on the expansion port?
Have you tried to measure the PHI2 signal with a logic analyzer or oscilloscope?

lordoftears, 2021-09-27:
Unfortunately, I do not have a logic analyzer or oscilloscope, sorry, I cannot be useful in this.
When I encountered the problem at the beginning, I checked with the tester all the connections of the expansion port. The voltage is correct, also other paths seem to be ok. The Ultimate-2+ cart works well, as well as "normal" cartridges.
Also the KFF works, I just have this issue when pressing the menu button, not each time, but often. I also checked the KFF with other computer, it works fine.

ogg1e, 2021-09-27:
I was seeing the same issue on my c64c.  I think it's the expansion port, really. Pushing down on those buttons moves the cart enough to cause things to go bad.   Either we need a new case design so that it has legs that allow the cart to rest on the desk to take the pressure off the port, or KFF needs to have the buttons moved to the backside instead of the top.

KimJorgensen, 2021-09-27:
@lordoftears I don't know about the Ultimate-2+ but most "normal" cartridges do not use the PHI2 signal. It is hard to get to the bottom of this without the ability to measure the signal.

@ogg1e That could explain a problem with the menu button but hardly why the frequency would be unstable when not touching the cartridge.

lordoftears, 2021-09-28:
This evening (CEST Time) I will try on an original C64c, both the menu button that the clock issue.

lordoftears, 2021-09-28:
As I supposed, it works like a charm on my C64c. Frequency fixed at 985214, no menu button issue.

KimJorgensen, 2021-09-28:
@lordoftears Great that it worked on your C64C. Did you use the same power supply for these tests?

Just for info; some have problems with the C64C (see https://github.com/KimJorgensen/KungFuFlash/issues/89) while others have problems with the expansion port connection when pushing the buttons as @ogg1e wrote (see https://github.com/KimJorgensen/KungFuFlash/issues/77)

lordoftears, 2021-09-29:
@KimJorgensen, thank you for the infos. I've used an angled adaptor for the expansion port, because at the beginning I thought it could be the problem. I am following also the other threads.
The PSU are different: a Keelog for the Sixty Clone and an old one of a C64c for the other original C64s (the breadbin and the C64c).

I must try with the same PSU. Anyway, the button menu issue on the Sixty Clone was experienced also with the other PSU.

KimJorgensen, 2021-09-29:
@lordoftears OK, thanks for info.
Regarding the PSU, I was trying to guess why the measured frequency would be wrong and was speculating if that due to noise on the clock signal coming from the power supply. But since you already tried another PSU with the Sixty Clone it can't be that.

However, looking at the service manual for the C64 I can see that the 5V supply for the clock circuit actually is regulated by VR2 on the main board. Do you have a regular 7805 installed as VR2 on the Sixty Clone or are you using some replacement?

lordoftears, 2021-09-29:
I tried anyway with the other PSU, same result.
I made a video about the clock diagnostic to show you the "oscillation". [https://we.tl/t-5slW4hTJW0]

I used a regular 7805 (I took the parts kit from Run Stop Re-Store as I think most of the people having built a SixtyClone).
[https://www.dropbox.com/s/1mjhd0qh7wdb46t/IMG_20210601_222406154_HDR.jpg?dl=0](url)

KimJorgensen, 2021-09-29:
Thank you for the video and picture.
When I read that the frequency was moving between 887450 to 987750 Hz it sounded much more dramatic than shown in the video, where the frequency was moving between 989076 and 989219 Hz.

This had me wondering if this oscillation just is a artifact of the clock circuit being misaligned. Do you know if the clock frequency was adjusted after the board was assembled?

lordoftears, 2021-09-29:
@KimJorgensen I am really sorry, I mistyped the first digit of course... 😕

When I assembled the board, I had black and white image on my 1084s, I adjusted a bit the trimmer and it displayed correctly.

KimJorgensen, 2021-09-29:
@lordoftears Don't worry about it :)

I don't know how accurate the frequency needs to be for the 1084, so I'm not sure what that implies.
Unless somebody else has some insights, I don't think we can get bottom of this unless you somehow measure the Phi2 signal to tell if the frequency is indeed unstable or if KFF has trouble detecting the signal.

lordoftears, 2021-09-29:
I have a multimeter capable of measuring clocks, but I don't think it is accurate at the precision needed. Unfortunately, I cannot afford  an oscilloscope at the moment, I mostly a game player, but if I can find some friend here having that I'll check it. Anyway, I'll try with the multimeter in any case. Apart from this issue on this specific computer, the KFF is something incredible for a game player like me.

KimJorgensen, 2021-09-29:
Glad that you like it.
If there is a bug I'll be happy to fix it, but unfortunately it is really hard to do remote debugging

lordoftears, 2021-10-04:
>
>
> Glad that you like it. If there is a bug I'll be happy to fix it, but unfortunately it is really hard to do remote debugging

I know, I hope to be helpful soon, I think everybody here appreciates the great work you did.

lordoftears, 2021-11-15:
@KimJorgensen I was able to perform some tests:

- replacing the new PLA with an original one, I have the same issue
- with the new firmware, it moves a bit in the rage of 986000Hz and 986200Hz or something like that. Less than before.
- Unfortunately I don't have a sharper tool with more digits, but the clock measured with my multimeter is fixed at 985. 2 MHz

Gabeki17, 2021-11-26:
Hi,

I have one device where the clock is 985119. And it is terrible.

There is a game that might be is the best to test it out.
It is Jupiter lander CRT version.

It is not only sparkling, but the sparkles are even coliding with the lander. :)
Also it goes even worst if warming up. So you die almost instantly.

Is Kungfu checks clock regularly so it can autotune it? Or only on bo

https://user-images.githubusercontent.com/4869862/143604921-fdae42e6-afe1-4e9f-be6c-f4fe75c9995c.mp4

oting?

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

KimJorgensen, 2021-11-28:
@Gabeki17 You could try adjusting the frequency to around 985248 Hz but I doubt this will do much difference. As I already told you in #94; It is probably the KFF that can't meet the timing requirements of the VIC-II on your specific C64.

You could try Jupiter Lander V2 in [this release](https://csdb.dk/release/?id=210760) and see if it works any better. If it does, maybe I can improve the Ultimax mode for normal cartridges as I did for Easyflash. Remember to start the EF cartridge in VIC-II/C128 mode via shift+return.

I would like to keep each issue to one topic so if your clock values is not unstable please keep the discussion to #94

gletonai, 2021-11-29:
My issues on ALDI C64 stopped manifesting with 1.29p, god job.

Gabeki17, 2021-11-30:
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

Thx!,

It also effects other games, like Prince of Persia. (Actually I bought KFF because of. :( )

I would try to tune it, but can't compile the code.
If you can help me with that I could try to solve my own issue, and when it works I can simply give you the information about.

I know there are many C64 behaving a litlle different.

Thank you in advance!

With regards,
Gábor

KimJorgensen, 2024-12-29:
I assume that the original issue was due to a timing problem that can be fixed by adjusting the phi2 offset. Otherwise feel free to create a new issue

Closed 2024-12-29.

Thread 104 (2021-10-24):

Bricked device with firmware update

pff729, 2021-10-24:
I successfully bricked my KungFuFlash.
I tried to update the firmware from 1.23 to 1.27 (both PAL versions). I've updated the firmware before and it went flawlessly: finished in a couple of seconds. But now, I've connected my KungFuFlash to my C64, opened the update file from the microSD, it wrote "updating in progress" to the screen but then nothing happened. I waited 45 minutes, still nothing, so I powered it off. Now, if I plug it into my C64, there is no sign of life: the screen is black and flickering.
I'm not sure what caused this. The difference between versions was too big?
Can it be fixed somehow? Maybe writing a firmware on it through the usb port? Or desoldering and swapping some parts? Or is it bricked forever?

KimJorgensen, 2021-10-30:
Interesting. Now I’m pretty sure that the issue is caused by the changes to the detection of C64 clock signal. If the clock frequency is just outside the accepted range then the KFF will refuse to start but the LED would not blink rapidly.

Here is a new test firmware where two changes has been made:
1. The LED would always blink rapidly if the KFF refuses to start due the C64 clock frequency being out of range
2. The accepted frequency range has been extended a bit

@mofjel Could you try with this new firmware and  report back? Regardless if it works or not, it would be useful to know what frequency you got in the diagnostic tool (pressing the menu button for 2 seconds using v1.27 or the new firmware if it works)

[KungFuFlash_vTST4.zip](https://github.com/KimJorgensen/KungFuFlash/files/7446229/KungFuFlash_vTST4.zip)

mofjel, 2021-10-30:
I have tested the test firmware, and it works!
So I played around with it, using the final cartridge 3 and action replay 6. Ran some games and demos. Everything works as they should as far as I know. And special button as well.
Ran som cartridge games, and they also worked as they should.

I tried the 2 sec menu button press. The frequency did vary a bit for each time I used it.
Highest frequency was 985216Hz
Lowest frequency was 985190Hz
(I did it 3 times)

I did the update using my C64.
I can't find any issues with it using the test firmware, it just works.
I will play around with it some more, and if I notice something, I will report back.
But it's looking good.

KimJorgensen, 2021-10-30:
@mofjel That is good news, thanks for testing.
It seems that the issue was caused by a slightly unstable clock frequency in your C64 and a too restrictive frequency check in the KFF firmware.

If you think it is fun to do experiments, you could try to adjust the frequency closer to 985248 Hz and see if the frequency gets more stable. You would do that with R27 next to the VIC-II chip on a 250407 board.
Just note that the KFF is not a precision instrument, so the frequency reading is not 100% accurate, and if you get the frequency wrong you may lose color on your monitor.

I'll create a new v1.29 firmware release with the changes from vTST4.

KimJorgensen, 2021-10-30:
A [new firmware](https://github.com/KimJorgensen/KungFuFlash/releases/tag/v1.29) has been release that fixes the problem reported by @mofjel

@pff729 I'm not sure if the issue you reported with v1.27 is related to the clock frequency detection. But if it is, and you have access to another C64 then you could try your bricked KFF with that.

pff729, 2021-10-30:
Thanks everyone for the help, I'm currently waiting for my ST-Link V2 programmer to arrive and hopefully I can unbrick my device as well.

mofjel, 2021-10-30:
@KimJorgensen I just want to thank you for taking the time and effort to solve this. And also, it was very fun to participate in this. And if you need help to test anything at a later time, just let me know. I will do it.
I have tweaked the frequency some, so it is closer to 985248 Hz.

@pff729 If you want to try the USB method, I have made a little step by step guide how to do this [here](https://everythingc64.boards.net/thread/1326/kung-fu-flash-usb-flashing)
All the information about how to do it, is out there. But I found it a bit hard to piece it all together. So I just wrote it down so maybe it can help someone.

Sebby75, 2021-10-31:
@mofjel
> I have made a little step by step guide how to do this

Thanks for this... Saved your guide and all tools needed to my KFF microsd card just in case, hopefully I will never need it.

Regards
Sebby75

pff729, 2021-12-20:
Thanks everyone for your help! I managed to unbrick my device with the USB method, installed version 1.32, it works flawlessly. Thanks @mofjel for your detailed guide for the usb method, it is really handy!

csico81, 2023-02-03:
> @KimJorgensen I just want to thank you for taking the time and effort to solve this. And also, it was very fun to participate in this. And if you need help to test anything at a later time, just let me know. I will do it. I have tweaked the frequency some, so it is closer to 985248 Hz.
>
> @pff729 If you want to try the USB method, I have made a little step by step guide how to do this [here](https://everythingc64.boards.net/thread/1326/kung-fu-flash-usb-flashing) All the information about how to do it, is out there. But I found it a bit hard to piece it all together. So I just wrote it down so maybe it can help someone.

Hi @mofjel
Do you still have your guide somehwere? The link does not work anymore. I am facing a similar issue that you had with the Kung Fu flash cartridge. I would take a look at your guide if is possible.
Thank you in advance,
csico

Shadowtrance, 2023-02-03:
> Hi @mofjel Do you still have your guide somehwere? The link does not work anymore. I am facing a similar issue that you had with the Kung Fu flash cartridge. I would take a look at your guide if is possible. Thank you in advance, csico

Salvaged via wayback machine (and corrected so links actually go somewhere).

------
1. Bridge the connection on J1 (+5v and USB) and bridge BOOTO and +3.3v on J4. Use a jumper to bridge this, because you need a way to remove the bridge after you are done. But you could solder in a jumper lead if you want.

2. Download DFU-UTIL http://dfu-util.sourceforge.net/releases/. It is called dfu-util-0.11.tar.gz.

3. You need to uncompress it twice using winzip. You should get a folder called dfu-util-0.11-binaries. You could rename the folder to something easier like DFU or something. Copy the folder to somewhere easy to find it. Like i.e C: or the root of some other HDD. Also copy the version of KungFuFlash firmware you want, into the Win64 or Win32 folder inside the DFU folder.

4. Go to Zadig https://zadig.akeo.ie/ and download the software there. Run it, and it will install the proper USB drivers for this to work. (At least it did for me) You might have to plug in the KungFuFlash for this.

5. Press WIN+R and type cmd in the window. Press enter and the command prompt should pop up.

6. Navigate to the DFU folder i.e: cd C:/dfu.

7. Navigate to the win64 or win32 folder.

8. Connect the KungFuFlash to the USB.

9. Type in the command prompt window: dfu-util -l  This command will list the compatible dfu devices connected. It found it? Good, now its ready to be flashed.

10. KimJorgensen has kindly typed in the command for flashing firmware, using dfu on his Github page https://github.com/KimJorgensen/KungFuFlash/blob/master/firmware/README.md. You can copy paste it into command prompt, but have to change to the correct firmware name.
      ie: dfu-util -a 0 -s 0x08000000 -D KungFuFlash_v1.29_PAL.upd and press enter.

      The KungFuFlash should now be flashed.

11. When dfu-util has done it's job, you disconnect the USB and remove the two jumpers. And it will be ready for use.

csico81, 2023-02-03:
@Shadowtrance Thank you so much! I will give it a try once I get home. ;)

Closed 2021-12-20.

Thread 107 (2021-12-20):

EF3 write hangs

dikdom, 2021-12-20:
Writing a full disk image still fails (hangs) in fast mode.
When using the 'kernal' switch with the ef3usb.exe then the d64 transfer is OK, completes successfully. Can it be possible that the USB transfer is stable now but the fast image write code in floppy is not OK?
Interestingly when the kernal mode is selected the C64's border is striped for a moment on each sector but not in the fast mode.

Using with (C=) factory IEC cable and a calibrated to 300RPM floppy drive ("1541C") and a freshly formatted (well, several times) floppy disk.
Using latest KFF version (v1.32) and latest ef3usb.exe I just've grabbed from github.

BTW: the 'il' (interleave) switch doesn't work with the kernal switch. I think the kernal write could be speed up a little with some smart interleave (now it writes from sector 0 to sector 20/18/17 one by one) also..

KimJorgensen, 2021-12-20:
Have you tried this with KFF version v1.24? It would be nice to know if I have broken something since the issue (#22) was fixed or if there is indeed another problem.

dikdom, 2021-12-20:
Now I've tried (v1.24p) but write also fails in TURBO mode, and properly transfers image in KERNAL mode.
The READ image also fails in TURBO mode and passes in KERNAL mode... (I've written a disk image to disk in KERNAL mode, read it back also in KERNAL mode, compared and matches).

In TURBO mode (read) the PC console hangs at:
'Transferring image from C64. T: 2 S: 1'
while on the C64 console the asterisk is missing from t2 s1 (there are two '*' are missing from the t2 column. The s0 and s1)

KimJorgensen, 2021-12-20:
Thanks for testing.
I have just successfully written 4 disks in turbo mode with KFF v1.32 and do not have any issues. However, I do have the same problem if I use a NTSC C64 so maybe there is a problem with the write code as you suggested.

KimJorgensen, 2021-12-20:
Do you have access to another disk drive?
I just retested with a 1541-II drive without any problems but I don't have a 1541C drive. Maybe the drive code doesn't work correctly with that version?

dikdom, 2021-12-20:
Hm. I tried with an old style 1541 (pull-down lever? What is the terminology for that?) and I managed to transfer 3 d64 images within 1m40s each without any error.
So the conclusion is that the 1541C driver's firmware is not compatible with the fast transfer of the EF3...

Can you ask them to fix this issue? :)

dikdom, 2021-12-20:
No idea... The ROMs match, the large gate arrays match.
6522 vs 65SC22 but those should be identical..

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

uffejakobsen, 2021-12-21:
@dikdom I would suspect the G65SC22P - it is a CMOS version of the original NMOS 6522.
The G65SC22P CMOS version cannot drive as much current as the original NMOS 6522 - that could create timing issues when tight code (such as a fastloader) gets close to the limits...

dikdom, 2021-12-21:
Yeah, probably. But still, I don't get it. Commodore had MOS, his own chip fab, why did it use VIA chips from different source?

uffejakobsen, 2021-12-21:
It doesn't look like a repair job - so I think it is safe to say that the G65SC22P ICs are form the original assembly of the drive.
MOS had limited production capacity - so I would guess that other sources were pulled in during some kind of supply shortage.
I've also seen CBM use both Rockwell and UMC 6502 CPUs in their own floppy drives.

dikdom, 2021-12-22:
Okay, kind of mistery solved. Now we somehow should find an other drive equipped with this G65SC22P and check if that fails too...
Let me close this issue.

Closed 2021-12-22.

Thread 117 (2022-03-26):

all three LED come on and stay on, black screen

AdrianPilko, 2022-03-26:
all 3 button LED come on and stay on and menu browser doesn't load, just black screen, it did same on two different C64: the cartridge was brand new and with supplied SD card. Couldn't find anyone having same problem after a while searching google, I have emailed the seller. Also briefly tried looking at the source code here. Has anyone else had this problem? I don't expect support from here but thought it was worth a try.

If it's just a case "of it does this when the firmware is missing or corrupt", then that's fine I found instructions to reflash the firmware using dfu_util.

KimJorgensen, 2022-03-26:
It could be problem with the firmware or a hardware related issue.
I would rather not suggest anything that could void your warranty until you have an agreement with the seller

acj1971, 2022-03-27:
Im getting the same issue

AdrianPilko, 2022-03-27:
Also worth saying that the same thing happened with or without an sd card inserted

agodng, 2022-04-15:
Hi at all, this is my first write and I specify that I would like to thank Kim Jorgensen
i got a kungfuflash cartridge from tfw8b version 1.2 (without usb interface) it always worked perfectly after all firmware updates from 1.29 to 1.34, unfortunately the latest update version 1.25 an after 1.37 something went wrong
all the LEDs turned on and the c64 keyboard commands did not respond, very slow

I tried to put only the fw1.37.upg file on the microsd but when I tried to flash the firmware 1.37 it remains in black screen

now I bought a STM32 ST-Link to reprogram the eprom and I hope to solve, I will let you know if everything works with 1.37 through SWD

Closed 2024-12-29.

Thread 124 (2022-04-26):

_DMA / DOT Clk  (question/advice)

anonymouz, 2022-04-26:
(I'm not aware of a KFF forum, so I'll ask here, please redirect me if I'm wrong.)
(also... I'm a hardware beginner...)

The _DMA and DOT_Clk lines are not connected...

- What hardware and/or design change would you recommend to connect _DMA and support REU ?
- Could the DOT clk be used for bus timing instead of PHI2 ? Would it be more accurate?
- Did you use a development board? Which one?

Thanks,
Onno

uffejakobsen, 2022-04-27:
I'm not Kim -

As far as I remember there are not that many GPIOs left on the selected MCU model...

But you could sacrifice the LED - again as far as I remember that pin is 5v tolerant (I did not do and fact checks before writing this)

Running the current handler system on the dot clk will give a lot of challenges i think - but again Kim should know his design better than me :-)

/Uffe :-)

KimJorgensen, 2022-04-27:
There is already an issue for REU support with some comments https://github.com/KimJorgensen/KungFuFlash/issues/68

The DOT clock could be used but then it would not be possible to have the microcontroller generate the correct clock for the USB to work. There is also a phase shift between the clocks that changes when the C64 is getting warm (https://retrotinker.net/who-turned-the-clock/) which could cause problems, but this is not something that I have tested.

I did use a development board for a testing a few things but quickly moved on to my own PCB. It was just a random cheap board from AliExpress

KimJorgensen, 2022-05-13:
@anonymouz If you have further questions, feel free to post them in this thread https://www.forum64.de/index.php?thread/96247-kung-fu-flash-cartridge/ or create another issue

Closed 2022-05-13.

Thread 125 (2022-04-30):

Test with GD32F405RTG6 and DFU mode

repetto74, 2022-04-30:
I have mounted a GD32F405RTG6 on the Kung Fu Flash PCB.
I would like to program it via USB but despite having shorted J1 and B0 / +3.3v of J4 I cannot get in DFU mode with the Dfuse software.
Is there any way to force DFU mode or is GD32 clone not compatible with DFU mode?
I would like to explore all possibilities and trials before buying an ST link V2 programmer.
Thanks
Rick

jgilcas, 2022-05-03:
I have tried with two of them, they programmed well (I did it with the stlink v2) even the led blinked but in the C64 always black screen, I don't know if they are the two of mine that are false or that they are not totally compatible.

jgilcas, 2022-05-03:
I tried with DFU also but the drivers issue is different, you have to install the GD32 DFU drivers, the STM32 ones are not valid.

repetto74, 2022-05-03:
Hi Kim
That’s s bad news indeed 😞. I heard that this GD32 does not seem to be a valid replacement for the STM32 equivalent.
That’s bad as I do not really know when this chip will be available again.
I can try my luck with the STlink V2 programmer but I think it will end with a non working KFF also for me.
Thanks for your feedback !
Rick

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

repetto74, 2022-05-03:
Hi Kim
Thanks I will update drivers with those suitable for the GD32 and give it a try.
I will report if I can successfully program it and test.
Thanks.

Rick

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

repetto74, 2022-05-06:
Yes I think that's a fact :-(. I have ordered an STM32 also and hope to
resolve it then ;-).

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

--
Riccardo Repetto
@ AppleWorld...

chuckcaley, 2022-05-10:
I to have tried the GD32 and all i got also was a blank screen and a blinking led. Programmed ok on the STlink.

repetto74, 2022-05-10:
Hi chuckcaley,
Conclusion is that GD32 is not a direct replacement for the SMT32 at least not for the KFF project.
Grab an SMT32 and it will work good ;-).

KimJorgensen, 2022-05-13:
Thank you for testing this.
I have added a note to the [release](https://github.com/KimJorgensen/KungFuFlash/releases/tag/rev.2) that the GD32F405 will not work as a replacement

Sgw32, 2022-06-04:
Any chance GD32 version will exist?
I've ordered 10 pcs cartridges not so long ago and now I'm struggling with the same trouble 😄
I'll start debugging it this summer but I'm not sure I'll do it until the end. Here is an errata for GD32F405:

http://easyelectronics.ru/img/ARM_kurs/STvsGD/Migration/compatibility%20sumup%20between%20GD32%20and%20STM32_V2.0.pdf

repetto74, 2022-06-04:
Just to confirm the incompatibility again. I have replaced the GD32 with the STM32 and now the KFF will just work flawlessly on first boot :-)

Sgw32, 2022-06-04:
Yes, but STM32 chips are now expensive and hard to find.

repetto74, 2022-06-04:
I sourced it from Aliexpress for 12 euro which is still acceptable if you are not producing large quantities.

Sgw32, 2022-06-04:
It's good, but often they supply defective parts along with working - and that's what I really beware. Especially AVR series, but STM32 too. Anyway LCSC is still better but more expensive.
And it allows automated assembly.

repetto74, 2022-06-04:
Here is the Aliexpress shop where I sourced the STM32.
https://www.aliexpress.com/item/1005003616330034.html?spm=a2g0o.order_list.0.0.7ad01802IGFixS
Comments are positive and it looks they deliver genuine STM components.

Sgw32, 2022-06-04:
Thanks!
I have ~2-3 STM32s in my stock, however would be great to adopt GD32... I've started debugging and seems like it is stuck here:

if (!(TIM1->SR & TIM_SR_CC1IF) || TIM1->CCR1 < 160 || TIM1->CCR1 > 170)

CCR1 is 0 on GD32, TIM1 SR has bit CC1IF reset and that's why it does not work.

GD32 has TIM0 instead of TIM1, however *real* addresses in hardware are the same, same for  registers.
For now I do not know why it does not work. If someone can adopt GD32 to this project, I can pay for this work
@KimJorgensen do you have any ideas, maybe you can fix firmware for GD32 for some price?

KimJorgensen, 2022-06-06:
@Sgw32 No, I have never tried to use a GD32 and it is not really something that has my interest. However, if somebody manages to get it working I'll be happy to add a link to their port.

Sgw32, 2022-06-28:
After some work my colleague has found that ARR register is not set for GD32 and that's why it does not count 1 MHz clock. That was the first issue it just blinks. Now it looks like it boots and even reset is not zero, but there is still a black screen and GAME=0, EXROM=1. I hope we'll make a fix for GD32 soon, after that I'll publish PR.

Sgw32, 2022-07-07:
GD32 version is almost ready. Working +- correctly on C64(not C64C, there are some troubles on its motherboard). I'll make pull request within a week.
For now I've seen that at least EasyFlash cartridge is not functioning on it.

KimJorgensen, 2022-07-07:
@Sgw32 Just to avoid misunderstandings; I'm not interested in maintaining new variants of the Kung Fu Flash hardware and therefore will not accept such a pull request.
However, you are of course free to do your own fork, and as said, I'll be happy to link to that once you get it working

Sgw32, 2022-07-10:
@KimJorgensen @repetto74 here is GD32 version with a release file:
https://github.com/Sgw32/KungFuFlashGD32

You can mention it on a page if needed. Hardware is the same.

repetto74, 2022-07-10:
Hi Sgw32 :-)

That awesome!! :-D. I will mount another KFF with the GD32 I have in stock and give it a try. I can be the Beta tester and report how it works.

repetto74, 2022-07-10:
Is there already a patched firmware available or do we need to compile it?

Sgw32, 2022-07-10:
Check releases

KimJorgensen, 2022-07-10:
@Sgw32 Great. I have added a link to your fork here https://github.com/KimJorgensen/KungFuFlash/releases/tag/rev.2

repetto74, 2022-07-10:
Got it! Thanks Sgw32 :-D!

Closed 2022-05-13.

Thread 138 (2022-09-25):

PC can't see KFF usb serial device

jperrin72, 2022-09-25:
Hi, I'm trying to use the ef3usb tool but the KFF is not recognized on the PC end.

Using Windows 11 device manager, I can't see any new device appearing, I tried to force serial driver installation using Zadig tool but no chance.

I also tried using a rpi4 running ubuntu, lsusb shows no usb device.

Then I tried different KFF firmware version, from latest (1.43) to older ones like 1.36 or 1.24. No chance.

Finally I started to check if my KFF PCB was routing correctly signals to the micro usb, both gnd and +5v are connected, I could also trace the D+/D- signals to related STM32 cpu pins...

What I am doing wrong ?

Thanks for your support

Jerome

jperrin72, 2022-09-26:
Update: I did more investigations and found that one of the D+/D- signals was not going through the connector to the pcb. A bad solder was the culprit. Re-done all the solders on the micro-sd connector and nailed it.

Closed 2022-09-26.

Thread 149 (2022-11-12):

Feature request: USB port for MIDI

hippi-viking, 2022-11-12:
I was wondering if it would be possible to use the USB port for MIDI in-output while outside of the firmware menu. It would make a lot of sense for ex. Prophet64 and would replicate the function of the Kerberos cartridge quite well.
(I don't know how helpful it might be but there is an [ARM-based cart](https://github.com/anarkiwi/vessel) for this, though it is wired differently than what is considered to be [*the standard*](https://codebase64.org/doku.php?id=base:c64_midi_interfaces).)

KimJorgensen, 2022-11-16:
It sounds like something that could be done, but I don't have much experience in this area.

Which MIDI interfaces does Prophet64 support? I can only find a reference of an interface that is connected to the user port, which does not correspond to what your refer to as the standard.

On the PC side, should the USB port show up as a different device (something other than a serial port)? And which software would it make sense to use here?

mwedmark, 2022-12-05:
With a software bridge as for example this: https://projectgus.github.io/hairless-midiserial/
I think the last idea seem promising, thus just open the serial port for this and use it both ways. This would be a really intereseting project to implement. It does not include any new hardware and also not new drivers for USB I guess. The hairless also seem to handle latency issues and buffer up/out to support different baud rates which in that case make it even simpler, just use anything faster f.e. 115200. Only downside that this solution always include a computer in between (C64 and synths/racks), but I guess that could be a small PI-Zero?

hippi-viking, 2022-12-06:
@mwedmark It sounds like a good compromise / first step. I don't know (yet) how difficult it is to implement USB host mode on the STM32F405 - and how problematic it is to switch to device mode when in the firmware menu (for the KungFuFlash _and_ the connected equipment!) -, so a USB host (which could very well be a RasPI) would be needed anyway at least while host mode can be implemented on the KungFuFlash to connect MIDI equipment. The downside is of course the added complexity.

hippi-viking, 2022-12-12:
I just found [this library](https://github.com/ripxorip/stm32_usb_midi), which seems to be a great candidate. I don't know yet how to interface it with the C64 though.

hippi-viking, 2024-03-02:
Hi Alex,

Sadly I didn't have much time, I am still learning to program the STM32. But there is a lot of hope, and quite a few of ready-made libraries to make it happen! I can't promise an ETA, but it is on my backlist to make the KFF a Midi interface one day.

You would need an USB-DIN adapter if you intend to use a Midi keyboard/device with the oldschool round plugs - which adapter could also be an STM32.

alexrepp, 2024-03-02:
Hi Hippi-Viking,
thanks for the response and good to hear :)
I don't have oldschool round plugs (anymore) - just two USB Keyboards.
Seen a TeensyROM Cartridge some days ago, where it seems to be realized with that USB-MIDI ... but am totally out of money this times :/ and would really be a burner at that KFF :)
Best wishes,
Alex

hippi-viking, 2024-03-07:
Hey Alex,

That's a good find. The MIDI-part of Teensy firmware should be relatively easy to port to KFF. I'll have a look, but don't promise anything as I'm still very new to this all. The good news is that it is definitely possible to make the KFF a MIDI adapter.

SensoriumEmbedded, 2024-03-07:
Hope you'll give me credit if you do that.  ;)
Might want to check out all the TeensyROM unique capabilities.  :)
Not putting down KFF at all, it's a great cart, just think there are complementary features.

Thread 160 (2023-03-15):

Stuck on "Communicating with usb"

Shadowtrance, 2023-03-15:
Yep my kung fu just decided to crap itself for no apparent reason. :(
Only thing different i did related to the cart today was install my arm2sid and listen to some tunes with it from the kung fu.
I've tried everything i can think of... no sd card, different blank sd card, reflashing firmware with dfu-util and STM32CubeProgrammer multiple times to no avail.
All i did before it happened was go back to the menu to load something else and i was greeted by that. (usb isn't connected)
Any ideas?

uffejakobsen, 2023-03-15:
From your description It is unclear to me what happens
- does the computer start up with KFF installed ?
- does it present anything when going into the KFF menu - is it garbled or not ?

Maybe some pictures will help us to help you..

Shadowtrance, 2023-03-15:
It seems to be trying to boot to the menu but instead of showing the menu it just has the usual menu border and bottom text but also has "Communicating with usb" yellow text and that's it. It doesn't go any further.
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

uffejakobsen, 2023-03-15:
I've taken a short look at the code - for some (currently) unknown reason the code does not see the expected KFF_ID_VALUE on an IO address - and continues into a EF3 main control loop where it was expected to go into a KFF main control loop...

It is a long shot - but have you tried to remove and reinsert your KFF cartridge ? maybe cleaning the PCB contacts ?

Also as we a dealing with around 40 years old computers here - they may suddenly break without notice
Do you have any other cartridges that you could test in the same computer - it could be a contact in your cartridge port that does not connect anymore...

Shadowtrance, 2023-03-15:
Yeah i tried the obvious things, taking it out, cleaning etc etc.
And being 40 would be a good point....but the only 40 year old parts in this system now are the cpu, cia's, basic and char roms and it's a rebuild to replace my "real" old one that was beyond repair.

And yeah other carts seem fine. I tried an original jupiter lander, some versa64 carts, sidekick64. No problem there.
This is really weird. Just seems to be stuck in that state and doesn't want to come out of it. :(

Shadowtrance, 2023-03-15:
Yeah i believe i do. arm2sid connects to IO1 and IO2 (mine is the single socket wired version) via a couple of diodes and pullup resistor (to 5v).
It's just really weird that it WAS working fine as i was listening to some 3 sid and other sid tracks off the KFF after installing the arm2sid earlier....then it crapped itself when i went to go back to the menu to load something else and has been stuck since.

But one thing i didn't try for some reason...but just thought to do now, disconnected the arm2sid cable (chip still in socket) and KFF booted once or twice, but totally random and usually just garbage half readable text on screen. Also managed to run the diagnostic and it says my Phi2 freq is 985148. (PAL system)

I'm just putting it down to "something on this particular cart has gone bad...and i don't know what" as everything else is working perfectly fine. I'll figured it out one day.

uffejakobsen, 2023-03-15:
KFF needs the IO1 line working in order to get into the menu
From your statement above - I'm having a hard time figuring out if the problem is solved or not ?

Shadowtrance, 2023-03-15:
Problem isn't solved, no.

IO1 is working as everything else works no problem. In particular Sidekick64 which also has a menu like KFF (which while I can't confirm, probably uses a similar way to load it and I'm guessing needs IO1 also as it has a lot of tricks up it's sleeve).

Arm2sid also uses IO1 and IO2 which is also working as it should.

So I'm thinking something with "my" particular KFF has gone bad somewhere and not an actual system problem.
I'm just as confused as you are tbh lol

pigravity, 2023-03-15:
Personally i would blame contacts, pins somewhere on the board, USB pins or STM pins might have shortcut.

Shadowtrance, 2023-03-17:
Yeah i can't figure out what's going on with it tbh.
Something has decided to go wrong with it and it's just stuck. No amount on flashing or running over joints with the iron/flux to freshen it up makes any difference.
I've had it for about a year and a half and no real issues to speak of until now which has just left me scratching my head.

KimJorgensen, 2023-03-17:
To troubleshoot this I would try to figure out if it is the KFF, the C64 or the combination of these that is the problem.

Some things you could try if possible:
1. Try the KFF with another C64
2. Try another KFF with your C64
3. Try a cartridge that requires I/O1 e.g. a freezer or fast load cartridge with your C64
4. Reverse everything you did when installing the arm2sid and see if the KFF is working again
5. Try adjusting the phi2 clock offset as Uffe suggested
6. Measure the I/O1 signal on the expansion port using an oscilloscope or logic analyzer

Shadowtrance, 2023-03-17:
1, 2 i couldn't do (only 1 kff and 64)
Yeah i noticed earlier that freezers weren't starting with my sidekick64 but i didn't think much of it. Now it kinda makes sense.

Reversed the arm2sid install entirely (which i'd already mostly tried before but left the 2 cpu lines but sid removed and disconnected) but the diodes and resistor for the 2 IO lines were still in place.

Once fully removed i tested again, still weird the first start but got into the kff diagnostic and did nothing and it's fine again and freezers are booting on sidekick64.

So...then i started the arm2sid install again but just the 2 cpu lines (A8 / A5), R/W Pin 5 cart port.
then for the IO lines instead of doing the "both" option i just did IO2 first alone (pin 10) - KFF normal
then IO1 alone (pin 7) - communicating with usb...
and obviously if i do both IO lines with the diodes/resistor it bugs out too.

How to fix that and still be able to use IO1? I don't know but i had to figure it out and make note of it as someone else may run into it one day and pull their hair out like i have. haha

uffejakobsen, 2023-03-20:
What board revision is your "sixtyclone" based on ? 250407/250466/250469 ?
And what PLA do you use in your setup ? original 906114-01 PLA (Signetics 82S100) or a PLA replacement ?

Shadowtrance, 2023-03-20:
250466 and PLAnkton pla.
The only original chips in there now are the cia's, cpu and basic/char roms. everything else is new stock (common logic etc) or modern replacements where possible. I do have an original pla around here somewhere which I'm pretty sure works (would have to test it)

uffejakobsen, 2023-03-20:
> I do have an original pla around here somewhere which I'm pretty sure works (would have to test it)

That would be interesting to test - I know the PLAnkton is aiming for compatibility - but still the original PLA may (all together with the resistor and diodes) drive the IO1/IO2 differently...

Shadowtrance, 2023-03-21:
Same result with the original pla with full wiring for arm2sid. This is really weird. but kinda expected when we're making the system do things it probably shouldn't be doing. Something is gonna clash somewhere at some point i guess.

uffejakobsen, 2023-03-21:
If I were you I would focus on the fact that even the "disconnected" setup does not work.
That means that the just pull-up resistor and diodes alone interferes with KFF operation.
You could try with a higher resister pull-up value that the recommended 3,3k - maybe 5k-10k ?

Once that is resolved - you could look at the full solution...

As a general rule of thumb - you have to remember

You cannot have ARM2SID (also) reacting on IO1 ($DE00-$DEFF) with KFF in the system

ARM2SID addresses seems to be configurable in `address mapping configuration` screen of the ARM2SID config utility..

Also if you are to use e.g. EasyFlash emulation in KFF - then IO2 ($DF00-$DFFF) will also be off limits for ARM2SID

Generally speaking - lots of freezer carts - WarpSpeed, Final Cartridge etc etc - most of them use IO1/IO2

Having ARM2SID reacting on the same IO signals would be a problem - unless ARM2SID access pattern to IO1/IO2 is extremely clever.

pazuzu72, 2023-07-10:
I don't know if it can be useful.
I get the "Communicating with usb" message with firmware 1.44 when I press **SHIFT + RETURN** and choose **LOAD** to run a **PRG**. If I use firmware **1.43** all ok instead. All chips are original and working, assy **250425** (tested on 4 C64), on the **C64C** instead no problem with **1.44**.

Closed 2024-12-29.

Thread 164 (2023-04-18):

Support for extra functionality to PS4-like remote reset

mwedmark, 2023-04-18:
STM32 is already controlling the C64 reset line and the idea here would be to control the whole flow of:
- Choosing Game
- Starting Game
- Playing Game
- Resetting to menu

remotely without ever touching the C64. The idea is to being able to continuously choose/look for a particular combination of extended joystick buttons from Kung Fu Flash firmware and upon getting the correct value resetting the C64 and returning to Kung Fu Flash menu and being able to select a new game. Far fetch idea so I use this issue to ask if there is something stopping this.

KimJorgensen, 2023-08-07:
I don't think this will be possible with the current hardware.
The additional joystick buttons needs to be read from the SID via the cartridge port, interrupting the running game at regular intervals. The KFF has no way of doing that (DMA line not connected) and even if it did, it may cause glitches or the game to crash.

However, it would be possible to create a small joystick adapter board with a wire to the menu button on the KFF

Closed 2023-08-07.

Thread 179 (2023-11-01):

Kung Fu Flash black/grey screen issue

steswart, 2023-11-01:
I have just built 4 x Kung Fu Flash cartridges using a STM32F405RGT6 chip. I managed to program the arm chip with the v1.48 firmware using DfuseDemo, but when I insert the cartridge in the c64 I get a black/grey screen. Could this be a fake STM32F405RGT6 chip I got from AliExpress? All 4 shows the same issue. The jumpers are not connected so it is not that.
Please let me know where I must start looking to get it working?
LED is dead as well. Polarity is correct as per PCB.

KimJorgensen, 2023-11-01:
I have no experience with fake or non STM chips, but if the LED is dead it could suggest that the chip wasn't programmed correctly.

For programming I would recommend a ST-Link V2 programmer, but you could check [these instructions](https://github.com/KimJorgensen/KungFuFlash/issues/70#issuecomment-753661669) to see if you did the same

steswart, 2023-11-01:
Hi KimJorgensen,

Thanks for the help. I followed the instructions using DFUDemo. Now the led turns on and reset button works, but i get no display. Same black/grey screen.
Could this be that am using a 22pf cap at c7 and c8 instead of a 20pf? I have ordered 20pf caps. Also getting a St-Link tomorrow

Sent from my iPhone

On 1/11/2023, at 20:48, Kim Jørgensen ***@***.***> wrote:

I have no experience with fake or non STM chips, but if the LED is dead it could suggest that the chip wasn't programmed correctly.

For programming I would recommend a ST-Link V2 programmer, but you could check these instructions<https://github.com/KimJorgensen/KungFuFlash/issues/70#issuecomment-753661669> to see if you did the same

—
Reply to this email directly, view it on GitHub<https://github.com/KimJorgensen/KungFuFlash/issues/179#issuecomment-1788547943>, or unsubscribe<https://github.com/notifications/unsubscribe-auth/APNMGDFQRAAVCIDKJDGNOC3YCH5EVAVCNFSM6AAAAAA6YTDUFWVHI2DSMVQWIX3LMV43OSLTON2WKQ3PNVWWK3TUHMYTOOBYGU2DOOJUGM>.
You are receiving this because you authored the thread.Message ID: ***@***.***>

KimJorgensen, 2023-11-01:
I'm not sure about C7 and C8, but if the LED turns on it indicates that the clock for the MCU is running.

Did you test with all 4 cartridges after reprogramming them? Else I would check the reset line to the C64 to see if it held low by the MCU.
If you have access to another C64 you could also test with that

steswart, 2023-11-02:
Hi Kim,

I reloaded the firmware using a ST-Link v2 on all 4, found some loose ARM legs on one and a badly soldered resistor array leg on another. So, I got 3 of the 4 working now. Will look at the 4th one later.
Thanks for your help 😊

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

Closed 2023-11-02.

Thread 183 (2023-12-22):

Insert SD-card issue

sonkite, 2023-12-22:
I have recently ordered 10 KFF v2 from jlcpcb.
Mounted all the components and flashed successfully with 1.48.

It works fine - for a while.... for all of them!

After that, like 30min plus, it says "insert fat formatted sd card".
Same issue for so far all of them except one, i think... havent fully tested all.

If i switch sdcard it doesnt help.

After issue presented it comes back earlier next time...
Exchanged sdcard reader on one..

Any suggestions? All 10 cant be faulty i presume...

Tested on 2 different c64c.
Testef 2 different sdcards.

Thanks in advance
Johan

KimJorgensen, 2023-12-23:
Hi Johan

Let me see if I understand what is happening: After using the Kung Fu Flash cartridge for 30+ minutes then it won't read the SD card anymore.
But then what? You reset the cartridge and it works again? Or you power off the C64 and it works again? Or the sdcard is totally dead and won't work again, but a new sdcard will until that also dies after 30+ minutes?

sonkite, 2023-12-23:
Sorry for being unclear.

It works for 30min.
After that it doesnt detect the card anymore.
Doesnt matter if I reset etc....only thung that helps it cooling off.
Sdcard works fine if I put it in the computer or another kff cart.

Same issue with all my 10 build kff carts.

Seems like some component is weakening with heat / current and I dont know where to look. Seems wierd that all 10 has the same issue.

Tested 2 different sdcards, 10 kff selfbuild (from same batch).

First test of a kff cart, it works for lika 30-60min.
After that it works less for every time, after some hours of cooldown

Tested 2 different c64c. Same problem so I dont think its the computer.

KFF diagnostics says Clock frequency at 985220.

Dont know where to look for failures. Some soldering? Some weak components?

KimJorgensen, 2023-12-24:
I have never experienced anything like that, and none of the components on the Kung Fu Flash cartridge seems to get hot at all.
Have you tried with a different power supply?

sonkite, 2023-12-26:
I have 1 original PSU (Light Grey version) and 1 brand new modern switched PSU. Tested both, same issue.

I have now made a new rest.
2/8 KFF works perfectly for 2h+.
6/8 KFF fails within 1,5h. After cooldown (waited like 3h, didnt check earlier) works again but eventuelly fails again within the same timeframe.

Tested them with same 2 sdcards, both computers, both PSU - no pattern as i can see.

I have replaced sdcard reader on 1 but sadly left it at work for the holidays so cant test it...

Sdcard reader bought at Aliexpress, weak quality?

Any soldering i should check except for the obvious ones at the cardreader? :)

Merry christmas,
Johan

pmandes, 2023-12-26:
Check the voltage drop after heating on the LDO, whole faulty batches happen. Show a photo of your boards. Reflow MCU will not hurt if it is a cold solder issue.

Best
Pawel

sonkite, 2023-12-26:
Thanks for your answers, both of you :)

Here comes the pictures.
I will try to measure tomorrow and reflow mcu.

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

sonkite, 2023-12-26:
Now measured U2.
From C64        After regulator U2
5.03V              3.31V       -- at start up
5.05V              3.31V       -- when failing the sdcard

"Right side of C2" - 3,31V
"Right side of C4" - 3,31V

UffeJakobsen, 2023-12-28:
Are the SDcards getting hot ?
Your test description does not tell if you also let the SDcard rest for hours before testing another unit ?
I come across some (fake?) sdcards that got extremely hot and eventually stopped working... the would seem work again after cooling down...

sonkite, 2023-12-30:
Its the same two SD-cards im using.
Dont let them cooldown and problem is not that since it works in another KF.

It might be the SD-card readers, have noticed that strange behaviors... tried to resolder and works temporarily sometimes. Tried to replace and got better before worse again (readers from the same batch).

I have ordered new readers but takes like a month...

CqaZ80, 2024-01-04:
rinse with white benzine for 1 hour ( into a glass container) and clean with a toothbrush from time to time... I got some strange behavior pretty similar to you, some flux remains can do some problems if you don't clean enough.

sonkite, 2024-01-04:
Thanks for your reply.

I've washed in ipa (isopropyl alcohol) and tried to reheat the connections... i will try another bath for one of the cards :)

sonkite, 2024-01-19:
Update:
It got better with 4h ipa bath and cleaning with a toothbrush every 30min :)
It was probably not enough with my first cleaning which i thought was very carefully.

Closed 2024-12-29.

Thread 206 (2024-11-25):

Multiload problems

lunadog, 2024-11-25:
I can load multiload CRT images from the One Load collection fine, but when I press the menu button I get "communication with cartridge failed" error. If I press menu enough times I can sometimes get back to the games list and switch to a single load which works fine.

This is with breadbin v1.51.
Have reproduced same issue on C64C.

lunadog, 2024-11-27:
Just tried to replicate today on C64C after cold boot and the problem is much more intermittent - only occurred 1 time out of 10. Completely baffled as to why.

KimJorgensen, 2024-11-27:
The issue you are describing could be caused by a bad connection to the C64, see #77
Try to clean the connector on the PCB and see if that helps

lunadog, 2024-12-02:
It only happens with the larger multiload one load images so I think it is more likely to be a timing error. I will see if there is any improvement with contact cleaning though

lunadog, 2024-12-02:
Just tried contact cleaning and no improvement (might be worse in actual fact). No issue with single load CRTs only multi-load.

Also affects another user - see post by Sebby75 here: https://www.lemon64.com/forum/viewtopic.php?t=76305&start=645

lunadog, 2024-12-02:
I've just downloaded to 1.31 (from 1.51) and multiloads work fine so must be a regression..

lunadog, 2024-12-02:
1.35 is the last version that doesn't have this bug. From 1.36 I get the error about 1 in 2 times (not as bad as later versions)

KimJorgensen, 2024-12-03:
Did you try to adjust the [phi2 offset](https://github.com/KimJorgensen/KungFuFlash/blob/master/firmware/README.md#diagnostic) with the newest firmware?
There was a lot changes to the timing in theres old releases, trying to make the cartridge work on as many C64s as possible

lunadog, 2024-12-03:
Hi - yep - phi2 offset on 1.51 didn't help. It is working perfectly with 1.31-1.36 so something must have happened to the code between 1.36 and 1.37 that broke it on my computer (not having looked at the code, maybe not waiting long enough for the cartridge to be ready?)

KimJorgensen, 2024-12-03:
Which phi2 offset values did you try?
As said, changes was done to the timing in theses releases and why I'm asking about the phi2 offset

lunadog, 2024-12-03:
I tried a number of different settings (+/- 3-5) up to the level that the
cartridge stopped being recognised. I am not really sure what settings I
would need to use though. The Phi2 numbers seemed to be around 100+
different from the target value but changing them more than 10 or so led to
the cartridge no longer being recognized from what I recall. I can do some
more extensive testing on this if you advise what phi2 values to try.

Best wishes,

James

On Tue, Dec 3, 2024 at 1:39 PM Kim Jørgensen ***@***.***>
wrote:

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

lunadog, 2024-12-03:
OK - I have tried all settings from -5 to +5, and there is no effect. I
also went back and tested the old firmware. I was incorrect about 1.36 -
the bug is still there. Version 1.35 works fine though.

On Tue, Dec 3, 2024 at 4:57 PM Kim Jørgensen ***@***.***>
wrote:

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

KimJorgensen, 2024-12-03:
OK, thank you for all your testing. Since I can't reproduce the problem
on my C64s, I need some more information to find the cause.
When you get the error, does it only say "Communication with cartridge
failed"? Or does the error message also say "Unexpected command" or
"Check hardware"?
What happens if you press reset after you get that error? What happens
if you power cycle the C64?

lunadog, 2024-12-03:
It just says communication with cartridge failed. If I press reset it
restarts the game (alien syndrome in this case).

If I cycle the power it restarts the game and still often gives the error
message when I press menu (maybe 7 or 8 out of 10 times).

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

KimJorgensen, 2025-01-04:
I found a race condition that could cause Kung Fu Flash to get stuck with the "Communication with cartridge failed" message. A fix has been included in the [latest release](https://github.com/KimJorgensen/KungFuFlash/releases/tag/v1.52) .
@lunadog Can you please report back if this indeed solves the problem?

lunadog, 2025-01-05:
Appears to now be fixed. Thanks so much!

Closed 2025-01-05.

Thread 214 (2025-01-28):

black screen :(

sokot123, 2025-01-28:
Hi,

I wanted to start by saying thank you for a great project.
I bought myself the parts to put the KFF together. It worked out :) (so I think)
Unfortunately it didn't want to program itself via ST-Link V2 nor via usb and the DFU-SE program. The computer either didn't see the usb device or the STM32 chip. However, I was able to program the chip with STM32CubeProgrammer using the USB method (via ST-link this program did not see the STM32 chip either). I tested it after programming by inserting it into a Commodore 64 without an SD card. The interface showed up so I was happy and put the device away for a few days until I bought a card and filled it with files. I did it i.... after inserting now in commodore i see only black screen. (It doesn't matter if there is an SD card or not). The reset button responds with an LED. Sometimes the buttons generate a rainbow image but usually they don't respond and there is only a black screen. I have checked on 3 of my commodore 64 and it is the same everywhere. with the STM32CubeProgrammer I can further connect to the chip via USB. It reads what is there and programs with different versions (I checked other versions to be sure). With the computer, however, it does not function. Do you perhaps have any advice for me ? I have the impression that I may have purchased a poor ST-Link V2 device that simply doesn't work and if I programmed with this method it would improve the situation. What do you think?

Best regards

KimJorgensen, 2025-02-18:
Hi,
It sounds like a hardware issue.
If you have built your own cartridge, I would recommend checking the solder joints with a microscope. If you built more cartridges, I would test with these as well.

/Kim

Closed 2025-03-08.

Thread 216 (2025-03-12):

Not able to switch to DFU mode to update

theshinyknight, 2025-03-12:
**Describe the bug**
Afer adding the jumper to J1 and J4 as per instructions (3.3v and boot0) , the cart does not go in DFU mode.

I get no windows "chime" when plugging the cart via USB, nor Dfuse see the cart as available DFU device.

If I remove the J4 jumper the cart does connect to the computer as I hear the chime (it shows as serial device), but that's all I can get, as it still does not show up as available DFU device.

**To Reproduce**
Steps to reproduce the behavior:
- Add J1 and J4 jumpers, then connect the cart to a windows pc

**Expected behavior**
The cart should go in DFU mode

**Kung Fu Flash (please complete the following information):**
 - Hardware: V2
 - Firmware: unknown as I do not have a working C64 yet (fixing my current C64); trying to flash on it the latest firmware

**Computer (please complete the following information):**
Windows 11 latest updates

KimJorgensen, 2025-03-13:
The bug cannot be reproduced and I assume it is a problem with your hardware.

I would recommend testing with a different USB cable and checking the solder joints with a microscope. If you built more cartridges, you could test with these as well.

If that doesn't help then try using the SWD interface for installing the firmware

Closed 2025-03-13.

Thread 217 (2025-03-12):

Problem with the “menu” button in Kung fu flash

sokot123, 2025-03-12:
Hi,

I've assembled myself a Kung fu flash on a rev.2 board and basically everything is running nicely except for one thing. When I turn on the game which is in some directory and try to exit back to the main menu with the button on the board artifacts appear on the screen. This only happens when I turn on a game that is in a directory. When I fire up a game that is in the main directory of the sd card the “menu” button works fine and the view returns to the start screen.

Here is what I have already done:
I have tested this on two C64 computers and on two SD cards. Is there anything else I can do before I start fixing the soldering on the PCB?

Best regards.

sokot123, 2025-03-12:
It looks like this

https://drive.google.com/file/d/1y0RmLIFZCyAxkHAGsq2T18XdBIPCn_XV/view

sokot123, 2025-03-13:
Hi,

I managed to find the cause. The “menu” and “special” buttons follow the 3.3V bus that supplies them with 3.3V, it goes through a diode and a resistor and enters the stm32 on pin 2 (from the diode) which was shorted to pin 3 (in the schematic it was called “game”). The short was not visible under the microscope, I could only detect it with a multimeter. I don't know how it was shorted to the point that I was sure that the stm32 chip had simply died, but I applied the desoldering tape a good few seconds and the short disappeared, and the KFF works 🙂

Best regards.

Closed 2025-03-13.

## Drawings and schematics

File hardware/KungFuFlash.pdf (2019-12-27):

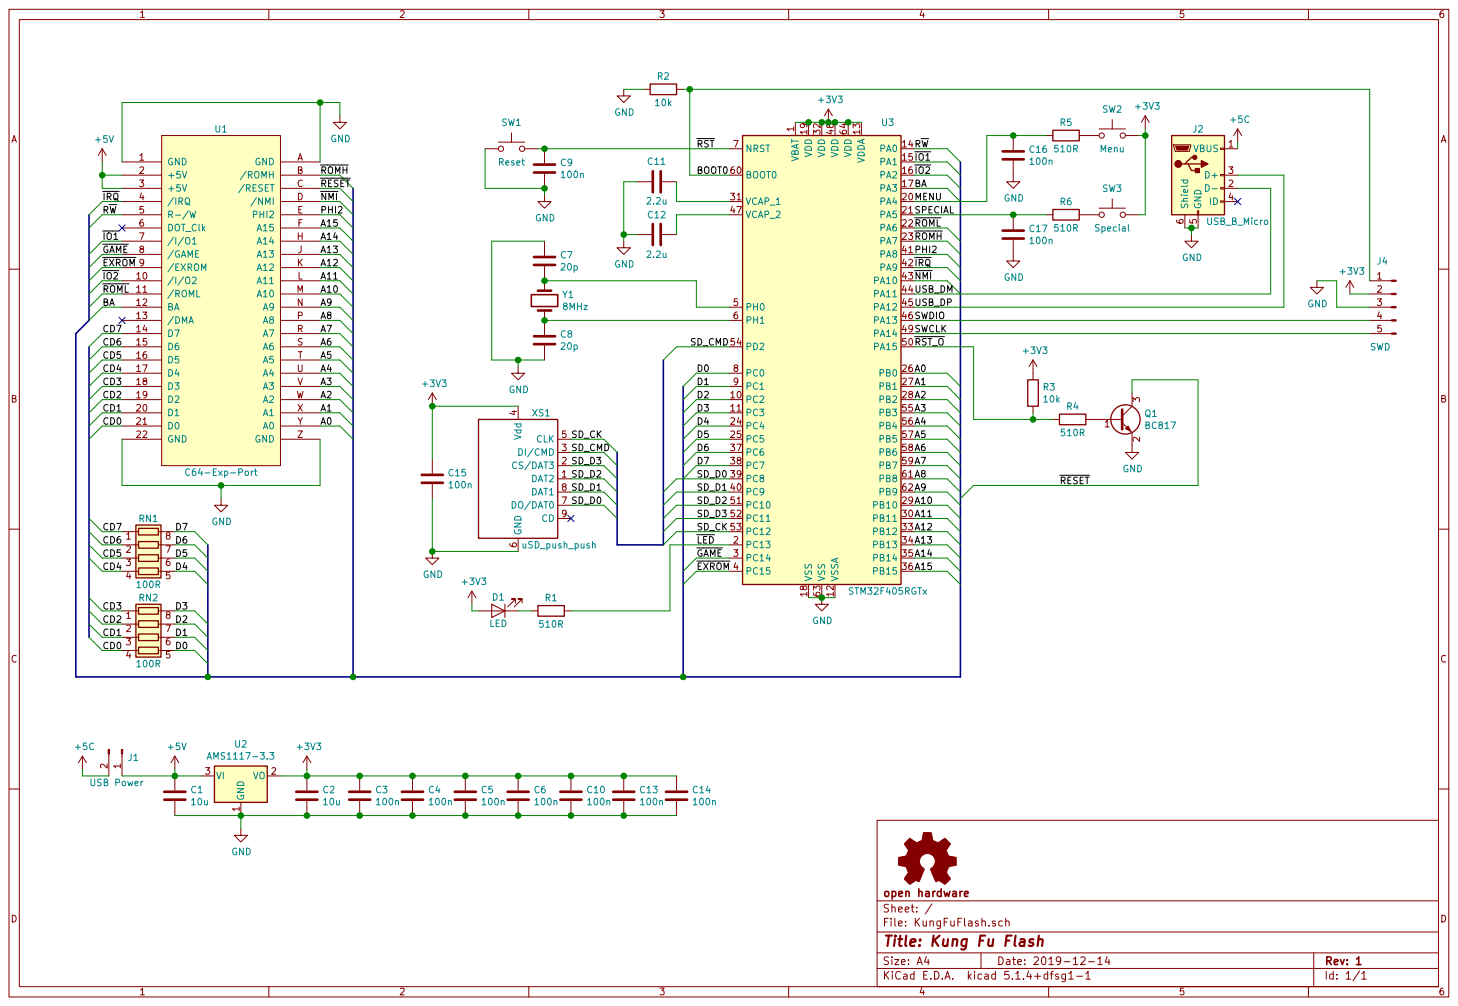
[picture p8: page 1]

1 VCAP_1 31 VCAP_2 47 VDD 19 VDD 32 VDD 48 VDD 64 VDDA 13 VSS 18 VSS 63 VSSA 12 U3 STM32F405RGTx GND 1

1 VO 2 VI 3 U2 AMS1117-3.3 DAT2 1 CS/DAT3 2 DI/CMD 3 Vdd

File: KungFuFlash.sch Sheet: / open hardware C15

Id: 1/1 Title: Kung Fu Flash

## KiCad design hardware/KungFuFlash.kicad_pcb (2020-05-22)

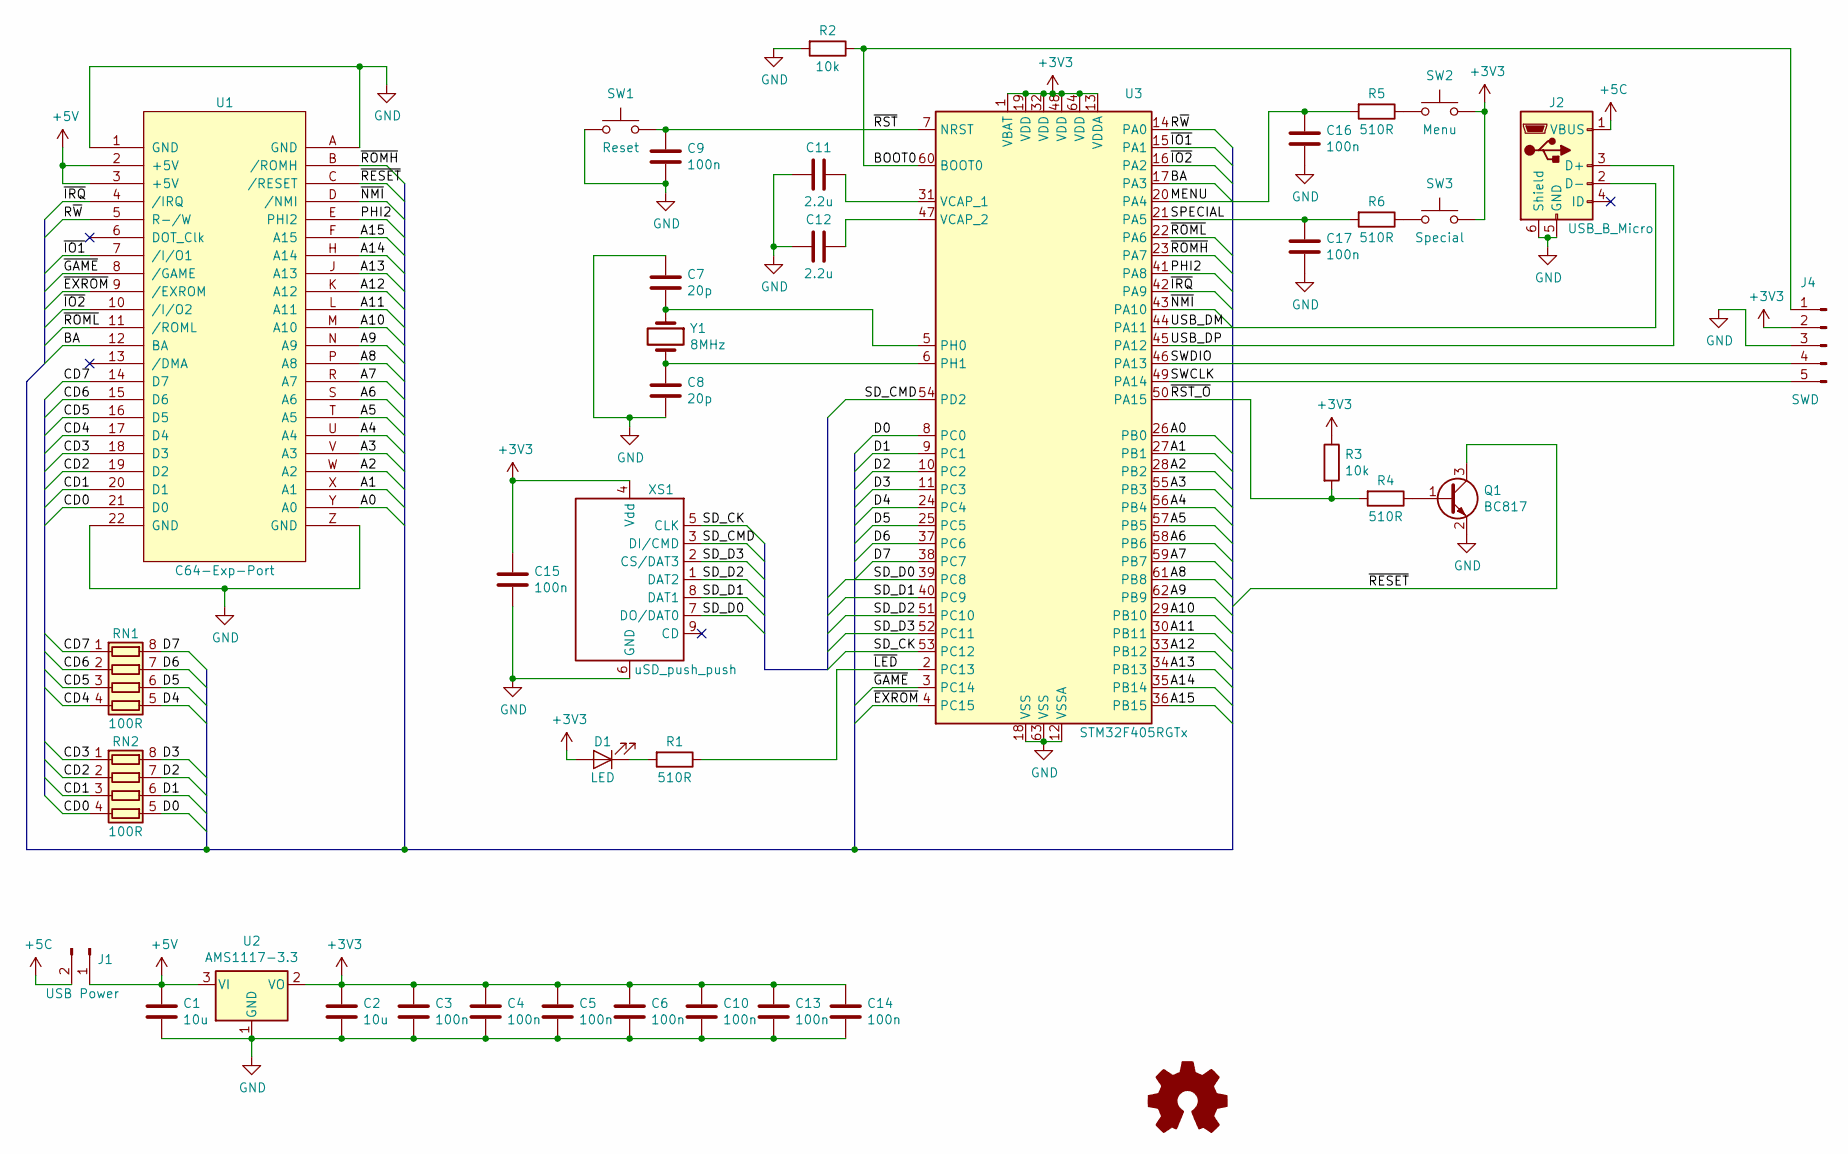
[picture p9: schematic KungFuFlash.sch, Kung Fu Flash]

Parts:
C1, C2: 10u; C_0805_2012Metric_Pad1.15x1.40mm_HandSolder
C3, C4, C5, C6, C9, C10, C13, C14, C15, C16, C17: 100n; C_0603_1608Metric_Pad1.05x0.95mm_HandSolder
C7, C8: 20p; C_0603_1608Metric_Pad1.05x0.95mm_HandSolder
C11, C12: 2.2u; C_0805_2012Metric_Pad1.15x1.40mm_HandSolder
D1: LED; LED_0805_2012Metric_Pad1.15x1.40mm_HandSolder
J1: USB Power; PinHeader_1x02_P2.54mm_Vertical
J2: USB_B_Micro; Conn_USBmicro-B_ebay-side_TH
J4: SWD; PinHeader_1x05_P2.54mm_Vertical
Q1: BC817; SOT-23
R1, R4, R5, R6: 510R; R_0805_2012Metric_Pad1.15x1.40mm_HandSolder
R2, R3: 10k; R_0805_2012Metric_Pad1.15x1.40mm_HandSolder
RN1, RN2: 100R; R_Array_Convex_4x0603
SW1: Reset; SW_PUSH_6mm_H8mm
SW2: Menu; SW_PUSH_6mm_H8mm
SW3: Special; SW_PUSH_6mm_H8mm
U1: C64-Exp-Port; C64-Cart
U2: AMS1117-3.3; SOT-223-3_TabPin2
U3: STM32F405RGTx; LQFP-64_10x10mm_P0.5mm
XS1: uSD_push_push; Conn_uSDcard
Y1: 8MHz; Crystal_SMD_5032-2Pin_5.0x3.2mm

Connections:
+3V3: C2.1, C3.1, C4.1, C5.1, C6.1, C10.1, C13.1, C14.1, C15.1, D1.2 (A), J4.2, R3.1, SW2.1, SW3.1, U2.2 (VO), U3.1 (VBAT), U3.13 (VDDA), U3.19 (VDD), U3.32 (VDD), U3.48 (VDD), U3.64 (VDD), XS1.4 (Vdd)
+5C: J1.2, J2.1 (VBUS)
+5V: C1.1, J1.1, U1.2 (+5V), U1.3 (+5V), U2.3 (VI)
/A0: U1.Y (A0), U3.26 (PB0)
/A1: U1.X (A1), U3.27 (PB1)
/A2: U1.W (A2), U3.28 (PB2)
/A3: U1.V (A3), U3.55 (PB3)
/A4: U1.U (A4), U3.56 (PB4)
/A5: U1.T (A5), U3.57 (PB5)
/A6: U1.S (A6), U3.58 (PB6)
/A7: U1.R (A7), U3.59 (PB7)
/A8: U1.P (A8), U3.61 (PB8)
/A9: U1.N (A9), U3.62 (PB9)
/A10: U1.M (A10), U3.29 (PB10)
/A11: U1.L (A11), U3.30 (PB11)
/A12: U1.K (A12), U3.33 (PB12)
/A13: U1.J (A13), U3.34 (PB13)
/A14: U1.H (A14), U3.35 (PB14)
/A15: U1.F (A15), U3.36 (PB15)
/BA: U1.12 (BA), U3.17 (PA3)
/BOOT0: J4.1, R2.1, U3.60 (BOOT0)
/CD0: RN2.4 (R4.1), U1.21 (D0)
/CD1: RN2.3 (R3.1), U1.20 (D1)
/CD2: RN2.2 (R2.1), U1.19 (D2)
/CD3: RN2.1 (R1.1), U1.18 (D3)
/CD4: RN1.4 (R4.1), U1.17 (D4)
/CD5: RN1.3 (R3.1), U1.16 (D5)
/CD6: RN1.2 (R2.1), U1.15 (D6)
/CD7: RN1.1 (R1.1), U1.14 (D7)
/D0: RN2.5 (R4.2), U3.8 (PC0)
/D1: RN2.6 (R3.2), U3.9 (PC1)
/D2: RN2.7 (R2.2), U3.10 (PC2)
/D3: RN2.8 (R1.2), U3.11 (PC3)
/D4: RN1.5 (R4.2), U3.24 (PC4)
/D5: RN1.6 (R3.2), U3.25 (PC5)
/D6: RN1.7 (R2.2), U3.37 (PC6)
/D7: RN1.8 (R1.2), U3.38 (PC7)
/MENU: C16.1, R5.2, U3.20 (PA4)
/PHI2: U1.E (PHI2), U3.41 (PA8)
/R~W: U1.5 (R-/W), U3.14 (PA0)
/SD_CK: U3.53 (PC12), XS1.5 (CLK)
/SD_CMD: U3.54 (PD2), XS1.3 (DI/CMD)
/SD_D0: U3.39 (PC8), XS1.7 (DO/DAT0)
/SD_D1: U3.40 (PC9), XS1.8 (DAT1)
/SD_D2: U3.51 (PC10), XS1.1 (DAT2)
/SD_D3: U3.52 (PC11), XS1.2 (CS/DAT3)
/SPECIAL: C17.1, R6.2, U3.21 (PA5)
/SWCLK: J4.5, U3.49 (PA14)
/SWDIO: J4.4, U3.46 (PA13)
/USB_DM: J2.2 (D-), U3.44 (PA11)
/USB_DP: J2.3 (D+), U3.45 (PA12)
/~EXROM: U1.9 (/EXROM), U3.4 (PC15)
/~GAME: U1.8 (/GAME), U3.3 (PC14)
/~IO1: U1.7 (/I/O1), U3.15 (PA1)
/~IO2: U1.10 (/I/O2), U3.16 (PA2)
/~IRQ: U1.4 (/IRQ), U3.42 (PA9)
/~LED: R1.1, U3.2 (PC13)
/~NMI: U1.D (/NMI), U3.43 (PA10)
/~RESET: Q1.3 (C), U1.C (/RESET)
/~ROMH: U1.B (/ROMH), U3.23 (PA7)
/~ROML: U1.11 (/ROML), U3.22 (PA6)
/~RST: C9.1, SW1.2, U3.7 (NRST)
/~RST_O: R3.2, R4.2, U3.50 (PA15)
GND: C1.2, C2.2, C3.2, C4.2, C5.2, C6.2, C7.1, C8.2, C9.2, C10.2, C11.1, C12.2, C13.2, C14.2, C15.2, C16.2, C17.2, J2.5 (GND), J2.6 (Shield), J4.3, Q1.2 (E), R2.2, SW1.1, U1.1 (GND), U1.22 (GND), U1.A (GND), U1.Z (GND), U2.1 (GND), U3.12 (VSSA), U3.18 (VSS), U3.63 (VSS), XS1.6 (GND)
unnamed: C7.2, U3.5 (PH0), Y1.1
unnamed: C8.1, U3.6 (PH1), Y1.2
unnamed: C11.2, U3.31 (VCAP_1)
unnamed: C12.1, U3.47 (VCAP_2)
unnamed: D1.1 (K), R1.2
unnamed: Q1.1 (B), R4.1
unnamed: R5.1, SW2.2
unnamed: R6.1, SW3.2

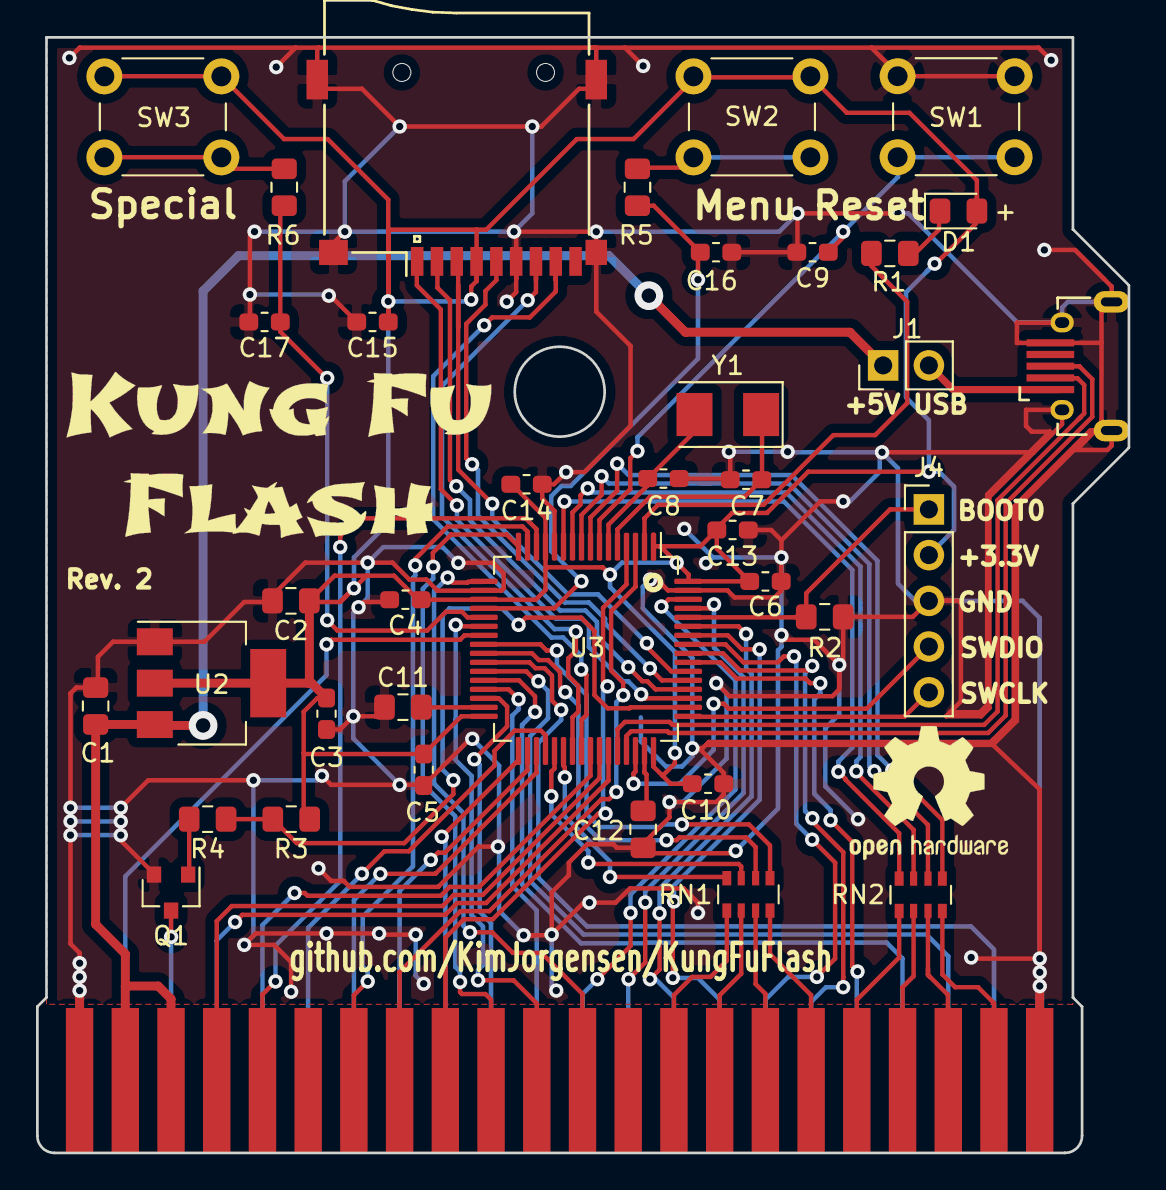
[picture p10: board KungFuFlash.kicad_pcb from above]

Board: 2 copper layers, 60.6 x 62.0 mm, 38 parts (0 on the bottom side), 72 nets.

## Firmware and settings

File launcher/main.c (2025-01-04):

/*
 * Copyright (c) 2019-2025 Kim Jørgensen
 *
 * This software is provided 'as-is', without any express or implied
 * warranty.  In no event will the authors be held liable for any damages
 * arising from the use of this software.
 *
 * Permission is granted to anyone to use this software for any purpose,
 * including commercial applications, and to alter it and redistribute it
 * freely, subject to the following restrictions:
 *
 * 1. The origin of this software must not be misrepresented; you must not
 *    claim that you wrote the original software. If you use this software
 *    in a product, an acknowledgment in the product documentation would be
 *    appreciated but is not required.
 * 2. Altered source versions must be plainly marked as such, and must not be
 *    misrepresented as being the original software.
 * 3. This notice may not be removed or altered from any source distribution.
 *
 ******************************************************************************
 * Derived from Draco Browser V1.0C 8 Bit (27.12.2009)
 * Created 2009 by Sascha Bader
 *
 * The code can be used freely as long as you retain
 * a notice describing original source and author.
 *
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
 * Newer versions might be available here: http://www.sascha-bader.de/html/code.html
 */

#include <stdio.h>
#include <string.h>
#include <stdlib.h>
#include <stdbool.h>
#include <ctype.h>
#include <conio.h>
#include <cbm.h>
#include <errno.h>
#include <joystick.h>
#include "screen.h"
#include "dir.h"
#include "base.h"
#include "kff_data.h"
#include "ef3usb_loader.h"
#include "disk.h"
#include "launcher_asm.h"

/* declarations */
static void mainLoopEF3(void);
static void mainLoopKFF(void);
static void textReaderLoop(void);
static uint8_t menuLoop(void);

static void updateScreen(void);
static void help(void);
static bool isSearchChar(uint8_t c);
static uint8_t search(uint8_t c);
static void showDir(void);
static void updateDir(uint8_t last_selected);
static void printDirPage(void);
static void printElement(uint8_t pos);

static const char *kff_read_text(void);
static void showKFFMessage(uint8_t color);
static void showMessage(const char *text, uint8_t color);

/* definitions */
#define EF3_USB_CMD_LEN 12

static bool isC128 = false;

static char linebuffer[SCREENW+1];
static char inputBuffer[SEARCH_LENGTH+1];
static char searchBuffer[SEARCH_LENGTH+1];
static uint8_t searchLen;
static uint8_t *bigBuffer = NULL;
static uint16_t *pageBuffer = NULL;
static Directory *dir = NULL;

// Use different name to bypass FW update check for NTSC users (prior v1.32)
#define KUNG_FU_FLASH_VER_UPD "Kung Fu Flash " ## KFF_VER " "
#define KUNG_FU_FLASH_VER "Kung Fu Flash v" ## KFF_VER

// Place program name in the start of the output file
// so it can be read by the firmware
#pragma rodata-name (push, "LOWCODE")
const char programNameVer[FW_NAME_SIZE] = KUNG_FU_FLASH_VER_UPD;
#pragma rodata-name (pop)

static const char programBar[] = {"          " KUNG_FU_FLASH_VER "           "};
static const char menuBar[] =    {"          " KUNG_FU_FLASH_VER "  <F1> Help"};

int main(void)
{
    uint8_t i, tmp, tst;
    initScreen(COLOR_BLACK, COLOR_BLACK, TEXTC);

    dir = (Directory *)malloc(sizeof(Directory));
    bigBuffer = (uint8_t *)dir;
    pageBuffer = (uint16_t *)dir;

    if (dir == NULL)
    {
        showMessage("Failed to allocate memory.", ERRORC);
        while (true);
    }

    if (joy_install(&joy_static_stddrv) != JOY_ERR_OK)
    {
        showMessage("Failed to install joystick driver.", ERRORC);
        while (true);
    }

    isC128 = is_c128() != 0;

    if (USB_STATUS == KFF_ID_VALUE) // KFF mode
    {
        mainLoopKFF();
    }
    else    // EF3 mode
    {
        // We can also end up here if there is a hardware problem
        // Test EF3 RAM to make sure we are indeed in EF3 mode
        tst = tmp = EF_RAM_TEST;
        for (i=0; i<=8; i++)
        {
            if (EF_RAM_TEST != tst)
            {
                showMessage("Communication with cartridge failed.", ERRORC);
                cprintf("Check hardware");
                while (true);
            }
            EF_RAM_TEST = tst = 1<<i;
        }
        EF_RAM_TEST = tmp;

        mainLoopEF3();
    }

    free(dir);
    return 0;
}

static void mainLoopEF3(void)
{
    uint8_t i;
    const char *cmd;

    // Get command from Kung Fu Flash cartridge using the EF3 USB protocol
    for (i=0; i<EF3_USB_CMD_LEN; i++)
    {
        cmd = ef3usb_check_cmd();
    }

    while (true)
    {
        if (cmd == NULL)
        {
            showMessage("Communicating with USB...", WARNC);
        }
        else if (strcmp(cmd, "prg") == 0)   // Load PRG
        {
            ef3usb_send_str("load");
            ef3usb_load_and_run();
        }
        else
        {
            showMessage("Received unsupported command.", ERRORC);
            cprintf("Command: %s", cmd);
            ef3usb_send_str("etyp");
        }

        while (!(cmd = ef3usb_check_cmd()));
    }
}

static void mainLoopKFF(void)
{
    const char *text;
    uint8_t cmd, reply, cxy[3];
    uint16_t cmd_wait = 0;

    // Get command from Kung Fu Flash cartridge using the KFF protocol
    while (!(cmd = KFF_GET_COMMAND()) || cmd >= REPLY_OK)
    {
        if (++cmd_wait > 10000)
        {
            cmd_wait = 0;
            showMessage("Waiting for command from cartridge.", ERRORC);
            cprintf("Command: %x", cmd);
        }
    }

    while (true)
    {
        reply = REPLY_OK;
        switch (cmd)
        {
            case CMD_NONE:
                break;

            case CMD_MESSAGE:
                showKFFMessage(TEXTC);
                break;

            case CMD_WARNING:
                showKFFMessage(WARNC);
                waitKey();
                kff_wait_for_sync();
                break;

            case CMD_FLASH_MESSAGE:
                showKFFMessage(TEXTC);
                textcolor(ERRORC);
                cprintf("PLEASE DO NOT POWER OFF OR RESET");
                kff_wait_for_sync();
                break;

            case CMD_TEXT:
            case CMD_TEXT_WAIT:
                kff_receive_data(&cxy, sizeof(cxy));
                text = kff_read_text();
                textcolor(cxy[0]);
                cputsxy(cxy[1], cxy[2], text);
                if (cmd == CMD_TEXT_WAIT)
                {
                    kff_wait_for_sync();
                }
                break;

            case CMD_TEXT_READER:
                textReaderLoop();
                wait_for_reset();
                break;

            case CMD_MENU:
                cmd = menuLoop();
                continue;

            case CMD_WAIT_SYNC:
                clrscr();
                kff_wait_for_sync();
                break;

            case CMD_MOUNT_DISK:
                disk_mount_and_load();
                break;

            case CMD_WAIT_RESET:
                wait_for_reset();
                break;

            default:
                showMessage("Communication with cartridge failed.", ERRORC);
                cprintf("Unexpected command: %x", cmd);
                break;
        }

        cmd = kff_send_reply(reply);
    }
}

static const char *kff_read_text(void)
{
    uint16_t size;
    kff_receive_data(&size, 2);
    kff_receive_data(bigBuffer, size);
    bigBuffer[size] = 0;

    return bigBuffer;
}

static void showKFFMessage(uint8_t color)
{
    const char *text = kff_read_text();
    showMessage(text, color);
}

static void showTextPage(uint16_t page)
{
    uint8_t i, chr, last_c = 0;

    clrscr();
    revers(1);
    textcolor(BACKC);
    cputsxy(0, 0, " >");
    KFF_READ_PTR = 0;
    for (i=0; i<DIR_NAME_LENGTH; i++)
    {
        cputc(KFF_DATA);
    }
    cputs("< ");
    cputsxy(0, BOTTOM, programBar);
    revers(0);
    textcolor(TEXTC);
    gotoxy(0, 1);

    KFF_READ_PTR = pageBuffer[page];
    while (true)
    {
        chr = KFF_DATA;
        if (!chr || wherey() >= 24)
        {
            (KFF_READ_PTR)--;
            break;
        }

        if (chr == 0x0a && last_c != 0x0d)  // Handle line endings
        {
            cputs("\r\n");
        }
        else if (chr == 0x09)   // Handle tab
        {
            if ((wherex() % 2) == 0)
            {
                cputs("  ");
            }
            else
            {
                cputc(' ');
            }
        }
        else
        {
            cputc(chr);
        }

        last_c = chr;
    }

    pageBuffer[page + 1] = KFF_READ_PTR;
}

static void textReaderLoop(void)
{
    uint8_t c;
    uint16_t size, page = 0;

    KFF_READ_PTR = DIR_NAME_LENGTH;
    kff_receive_data(&size, 2);
    size++;
    pageBuffer[0] = KFF_READ_PTR;
    showTextPage(0);

    waitRelease();
    while (true)
    {
        c = kbhit() ? cgetc() : getJoy();
        switch (c)
        {
            case CH_ENTER:
            case CH_SHIFT_ENTER:
            case CH_DEL:
            case CH_STOP:
                return;

            case CH_HOME:
            case CH_FIRE_LEFT:
            case CH_FIRE_UP:
                page = 0;
                showTextPage(page);
                break;

            case CH_CURS_DOWN:
            case CH_CURS_RIGHT:
                if (KFF_READ_PTR < size && page < (sizeof(Directory)/2))
                {
                    showTextPage(++page);
                }
                break;

            case CH_CURS_LEFT:
            case CH_CURS_UP:
                if (page)
                {
                    showTextPage(--page);
                }
                break;

            default:
                break;
        }
    }
}

static void updateScreen(void)
{
    clrscr();
    revers(0);
    textcolor(BACKC);
    drawFrame();
    revers(1);
    cputsxy(0, BOTTOM, menuBar);
    revers(0);

    showDir();
}

static uint8_t menuLoop(void)
{
    uint8_t c, last_selected = 0;
    uint8_t data, cmd, reply;

    memset(dir, 0, sizeof(Directory));
    updateScreen();

    cmd = CMD_NONE;
    kff_send_size_data(searchBuffer, searchLen);
    reply = REPLY_DIR;

    while (true)
    {
        if (cmd != CMD_NONE || reply != REPLY_OK)
        {
            cmd = kff_send_reply_progress(reply);
        }

        reply = REPLY_OK;
        switch (cmd)
        {
            case CMD_NONE:
                break;

            case CMD_READ_DIR:
                readDir(dir);
                showDir();
                waitRelease();
                continue;

            case CMD_READ_DIR_PAGE:
                if (!readDirPage(dir))
                {
                    dir->selected = last_selected;
                }

                if (dir->selected >= dir->no_of_elements)
                {
                    dir->selected =
                        dir->no_of_elements ? dir->no_of_elements-1 : 0;
                }

                if (dir->selected < dir->text_elements)
                {
                    dir->selected = dir->text_elements;
                }

                showDir();
                continue;

            default:
                return cmd;
        }

        c = kbhit() ? cgetc() : getJoy();
        switch (c)
        {
            case CH_NONE:
                break;

            // --- start / enter directory
            case CH_ENTER:
            case CH_SHIFT_ENTER:
                if (dir->no_of_elements)
                {
                    data = dir->selected;
                    if (isC128)
                    {
                        data |= SELECT_FLAG_C128;
                    }
                    if (c == CH_SHIFT_ENTER)
                    {
                        data |= SELECT_FLAG_OPTIONS;
                    }

                    KFF_SEND_BYTE(data);
                    reply = REPLY_SELECT;
                }
                break;

            // --- leave directory
            case CH_DEL:
            case CH_FIRE_LEFT:
                if (searchBuffer[0] && *dir->name != ' ')
                {
                    reply = search(c);
                }
                else
                {
                    reply = REPLY_DIR_UP;
                }
                break;

            // --- root directory
            case CH_HOME:
                if (searchBuffer[0] && *dir->name != ' ')
                {
                    reply = search(c);
                }
                else
                {
                    reply = REPLY_DIR_ROOT;
                }
                break;

            case CH_CURS_DOWN:
                if (dir->no_of_elements)
                {
                    last_selected = dir->selected;
                    if ((dir->selected+1) < dir->no_of_elements)
                    {
                        dir->selected++;
                        updateDir(last_selected);
                    }
                    else if (dir->no_of_elements == MAX_ELEMENTS_PAGE)
                    {
                        dir->selected = 0;
                        reply = REPLY_DIR_NEXT_PAGE;
                    }
                }
                break;

            case CH_CURS_UP:
                if (dir->no_of_elements)
                {
                    last_selected = dir->selected;
                    if (dir->selected > dir->text_elements)
                    {
                        dir->selected--;
                        updateDir(last_selected);
                    }
                    else
                    {
                        dir->selected = MAX_ELEMENTS_PAGE-1;
                        reply = REPLY_DIR_PREV_PAGE;
                    }
                }
                break;

            case CH_CURS_RIGHT:
                if (dir->no_of_elements)
                {
                    if (dir->no_of_elements < MAX_ELEMENTS_PAGE)
                    {
                        last_selected = dir->selected;
                        dir->selected = dir->no_of_elements-1;
                        updateDir(last_selected);
                    }
                    else
                    {
                        last_selected = dir->no_of_elements-1;
                        reply = REPLY_DIR_NEXT_PAGE;
                    }
                }
                break;

            case CH_CURS_LEFT:
                if (dir->no_of_elements)
                {
                    last_selected = 0;
                    reply = REPLY_DIR_PREV_PAGE;
                }
                break;

            // --- search
            case CH_INS:
            case CH_FIRE_UP:
                if (*dir->name != ' ')
                {
                    reply = search(c);
                }
                break;

            // --- clear search
            case CH_CLR:
                if (searchBuffer[0] && *dir->name != ' ')
                {
                    reply = search(c);
                }
                break;

            case CH_F1:
                help();
                break;

            case CH_FIRE_DOWN:
                if (searchBuffer[0] && *dir->name != ' ')
                {
                    reply = search(c);
                }
                else
                {
                    help();
                }
                break;

            case CH_F5:
                reply = REPLY_SETTINGS;
                break;

            case CH_FIRE_RIGHT:
                if (searchBuffer[0] && *dir->name != ' ')
                {
                    reply = search(c);
                }
                else
                {
                    reply = REPLY_SETTINGS;
                }
                break;

            case CH_F6:
                reply = REPLY_KILL_C128;
                break;

            case CH_F7:
                reply = REPLY_BASIC;
                break;

            case CH_F8:
                reply = REPLY_KILL;
                break;

            case CH_STOP:
                reply = REPLY_RESET;
                break;

            default:
                if (isSearchChar(c) && *dir->name != ' ')
                {
                    reply = search(c);
                }
                break;
        }
    }
}

static bool isSearchChar(uint8_t c)
{
    return (c >= 0x20 && c <= 0x5f) || (c >= 0xc1 && c <= 0xda);
}

static uint8_t search(uint8_t c)
{
    uint8_t cursor_pos, cursor_delay;
    bool changed = false;
    uint8_t i, last_selected = dir->selected;

    dir->selected++;
    printElement(last_selected);
    dir->selected = last_selected;

    textcolor(TEXTC);
    revers(1);
    memcpy(inputBuffer, searchBuffer, searchLen);

    for (i=searchLen; i<SEARCH_LENGTH; i++)
    {
        inputBuffer[i] = ' ';
    }
    inputBuffer[SEARCH_LENGTH] = 0;

    cursor_pos = searchLen < SEARCH_LENGTH ? searchLen : SEARCH_LENGTH;

    while (c != CH_ENTER)
    {
        if (c == CH_HOME)
        {
            cursor_pos = 0;
        }
        else if (c == CH_DEL || c == CH_FIRE_LEFT)
        {
            if (cursor_pos)
            {
                cursor_pos--;
            }
            else
            {
                break;
            }

            for (i=cursor_pos; i<SEARCH_LENGTH-1; i++)
            {
                inputBuffer[i] = inputBuffer[i+1];
            }
            inputBuffer[SEARCH_LENGTH-1] = ' ';
        }
        else if (c == CH_CURS_LEFT)
        {
            if (cursor_pos)
            {
                cursor_pos--;
            }
        }
        else if (c == CH_CLR || c == CH_FIRE_DOWN)
        {
            memset(inputBuffer, ' ', SEARCH_LENGTH);
            break;
        }
        else if (cursor_pos < SEARCH_LENGTH)
        {
            if (c == CH_INS || c == CH_FIRE_UP)
            {
                for (i=SEARCH_LENGTH-1; i>cursor_pos; i--)
                {
                    inputBuffer[i] = inputBuffer[i-1];
                }
                inputBuffer[cursor_pos] = ' ';
            }
            else if (c == CH_CURS_RIGHT)
            {
                cursor_pos++;
            }
            else if (c == CH_CURS_UP)
            {
                c = inputBuffer[cursor_pos] + 1;
                if (c < 0x2a)   // '*'
                {
                    c = 'a';
                }
                else if (c < 0x30)  // '0'
                {
                    c = '0';
                }
                else if (c > 0x39 && c < 0x41)  // '9' - 'a'
                {
                    c = ' ';
                }
                else if (c > 0x5a)  // 'z'
                {
                    c = '*';
                }

                inputBuffer[cursor_pos] = c;
            }
            else if (c == CH_CURS_DOWN)
            {
                c = inputBuffer[cursor_pos] - 1;
                if (c < 0x20)   // ' '
                {
                    c = '9';
                }
                else if (c < 0x2a)  // '*'
                {
                    c = 'z';
                }
                else if (c < 0x30)   // '0'
                {
                    c = '*';
                }
                else if (c > 0x39 && c < 0x41)  // '9' - 'a'
                {
                    c = ' ';
                }
                else if (c > 0x5a)  // 'z'
                {
                    c = ' ';
                }

                inputBuffer[cursor_pos] = c;
            }
            else if (isSearchChar(c))
            {
                inputBuffer[cursor_pos++] = c;
            }
        }

        sprintf(linebuffer, "> Search: %s <", inputBuffer);
        cputsxy(1, 0, linebuffer);

        cursor_delay = 0;
        while (true)
        {
            if (cursor_delay == 0)
            {
                SCREEN_RAM[11 + cursor_pos] ^= 0x80;
                cursor_delay = 120;
            }
            cursor_delay--;

            if (kbhit())
            {
                c = cgetc();
                if (c != CH_CURS_UP && c != CH_CURS_DOWN)
                {
                    break;
                }
            }

            c = getJoy();
            if (c)
            {
                if (c == CH_FIRE_RIGHT)
                {
                    c = ' ';
                }
                break;
            }
        }
        revers(1);
    }

    for (i=SEARCH_LENGTH; i>0; i--) // remove trailing space
    {
        if (inputBuffer[i-1] == ' ')
        {
            inputBuffer[i-1] = 0;
        }
        else
        {
            break;
        }
    }
    searchLen = i;

    for (i=0; i<=searchLen; i++)
    {
        if (searchBuffer[i] != inputBuffer[i])
        {
            changed = true;
            searchBuffer[i] = inputBuffer[i];
        }
    }

    if (!changed)
    {
        showDir();
        waitRelease();
        return REPLY_OK;
    }

    kff_send_size_data(searchBuffer, searchLen);
    return REPLY_DIR;
}

static void showDir(void)
{
    if (*dir->name == CLEAR_SEARCH)
    {
        searchLen = 0;
        searchBuffer[0] = 0;
    }

    if (searchBuffer[0] && *dir->name != ' ')
    {
        sprintf(linebuffer, "> Search: %-26s <", searchBuffer);
    }
    else
    {
        sprintf(linebuffer, ">%-36s<", dir->name);
    }

    textcolor(BACKC);
    revers(1);
    cputsxy(1, 0, linebuffer);

    revers(0);
    printDirPage();
}
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

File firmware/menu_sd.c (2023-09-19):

/*
 * Copyright (c) 2019-2023 Kim Jørgensen
 *
 * This software is provided 'as-is', without any express or implied
 * warranty.  In no event will the authors be held liable for any damages
 * arising from the use of this software.
 *
 * Permission is granted to anyone to use this software for any purpose,
 * including commercial applications, and to alter it and redistribute it
 * freely, subject to the following restrictions:
 *
 * 1. The origin of this software must not be misrepresented; you must not
 *    claim that you wrote the original software. If you use this software
 *    in a product, an acknowledgment in the product documentation would be
 *    appreciated but is not required.
 * 2. Altered source versions must be plainly marked as such, and must not be
 *    misrepresented as being the original software.
 * 3. This notice may not be removed or altered from any source distribution.
 */

static void sd_format_size(char *buffer, u32 size)
{
    char units[] = "BKmg";
    char *unit = units;

    while (size >= 1000)
    {
        size += 24;
        size /= 1024;
        unit++;
    }

    if (size < 100)
    {
        *buffer++ = ' ';
    }
    if (size < 10)
    {
        *buffer++ = ' ';
    }

    sprint(buffer, "%u%c ", size, *unit);
}

static void sd_format_element(char *buffer, FILINFO *info)
{
    *buffer++ = ' ';

    // Element name
    const u8 filename_len = (ELEMENT_LENGTH-1)-6;
    to_petscii_pad(buffer, info->fname, filename_len);
    buffer += filename_len;
    *buffer++ = ' ';

    // Element type or size
    if (info->fattrib & AM_DIR)
    {
        sprint(buffer, " dir ");
    }
    else
    {
        sd_format_size(buffer, info->fsize);
    }
}

static void sd_send_not_found(SD_STATE *state)
{
    to_petscii_pad(scratch_buf, " no files found", ELEMENT_LENGTH);
    if (state->search[0])
    {
        scratch_buf[0] = SELECTED_ELEMENT;
    }

    c64_send_data(scratch_buf, ELEMENT_LENGTH);
}

static u8 sd_send_page(SD_STATE *state, u8 selected_element)
{
    bool send_dot_dot = !state->in_root && state->page_no == 0;
    bool send_not_found = state->page_no == 0;

    FILINFO file_info;
    u8 element;
    for (element=0; element<MAX_ELEMENTS_PAGE; element++)
    {
        if (send_dot_dot)
        {
            file_info.fname[0] = '.';
            file_info.fname[1] = '.';
            file_info.fname[2] = 0;
            file_info.fattrib = AM_DIR;
            send_dot_dot = false;
        }
        else
        {
            if (!dir_read(&state->end_page, &file_info))
            {
                file_info.fname[0] = 0;
            }

            if (file_info.fname[0])
            {
                send_not_found = false;
            }
            else
            {
                // End of dir
                dir_close(&state->end_page);
                state->dir_end = true;

                if (send_not_found)
                {
                    sd_send_not_found(state);
                }

                send_page_end();
                break;
            }
        }

        sd_format_element(scratch_buf, &file_info);
        if (element == selected_element)
        {
            scratch_buf[0] = SELECTED_ELEMENT;
        }

        c64_send_data(scratch_buf, ELEMENT_LENGTH);
    }

    return element;
}

static void sd_dir_open(SD_STATE *state)
{
    // Append star to end of search string
    size_t search_len = strlen(state->search);
    if (search_len && state->search[search_len-1] != '*')
    {
        state->search[search_len] = '*';
        state->search[search_len + 1] = 0;
    }

    if (!dir_open(&state->start_page, state->search))
    {
        fail_to_read_sd();
    }

    state->end_page = state->start_page;
    state->page_no = 0;
    state->dir_end = false;
}

static void sd_send_prg_message(const char *message)
{
    c64_send_prg_message(message);
    c64_interface(false);
}

static void sd_send_warning_restart(const char *message, const char *filename)
{
    c64_interface_sync();
    sprint(scratch_buf, "%s\r\n\r\n%s", message, filename);
    c64_send_warning(scratch_buf);
    restart_to_menu();
}

static u8 sd_parse_file_number(char *filename, u8 *extension)
{
    u8 pos = *extension-1;
    if (pos <= 5 || filename[pos--] != ')')
    {
        return 0;
    }

    u8 number;
    if (filename[pos] >= '0' && filename[pos] <= '9')
    {
        number = filename[pos--] - '0';
    }
    else
    {
        return 0;
    }

    if (filename[pos] >= '0' && filename[pos] <= '9')
    {
        number += (filename[pos--] - '0') * 10;
    }

    if (filename[pos--] != '(' || filename[pos] != ' ')
    {
        return 0;
    }

    *extension = pos;
    return number;
}

static bool sd_generate_new_filename(void)
{
    char *filename = dat_file.file;

    u8 extension;
    u8 length = get_filename_length(filename, &extension);
    if (length <= extension)
    {
        return false;
    }

    u8 file_number = sd_parse_file_number(filename, &extension);
    if (++file_number >= 100)
    {
        return false;
    }

    if (length < (sizeof(dat_file.file)-5))
    {
        sprint(filename + extension, " (%u).crt", file_number);
        return true;
    }

    return false;
}

static void sd_handle_save_updated_crt(u8 flags)
{
    sd_send_prg_message("Saving CRT file.");
    if (!load_dat())
    {
        restart_to_menu();
    }

    if (!(flags & SELECT_FLAG_OVERWRITE))
    {
        bool file_exists = true;
        while (file_exists)
        {
            if (!sd_generate_new_filename())
            {
                if (!load_dat())
                {
                    restart_to_menu();
                }
                sd_send_warning_restart("Failed to generate new filename for",
                                        dat_file.file);
            }

            FILINFO file_info;
            file_exists = file_stat(dat_file.file, &file_info);
        }
    }

    FIL file;
    if (!file_open(&file, dat_file.file, FA_WRITE|FA_CREATE_ALWAYS) ||
        !crt_write_header(&file, CRT_EASYFLASH, 1, 0, "EASYFLASH") ||
        !crt_write_file(&file, dat_file.crt.banks))
    {
        sd_send_warning_restart("Failed to write CRT file", dat_file.file);
    }
    file_close(&file);

    // Updated flag is cleared so we need to calculate a new hash
    u32 flash_hash = crt_calc_flash_crc(dat_file.crt.banks);
    dat_file.crt.flash_hash = flash_hash;
    dat_file.crt.flags &= ~CRT_FLAG_UPDATED;
    save_dat();

    restart_to_menu();
}

static bool sd_crt_updated(SD_STATE *state)
{
    if (dat_file.boot_type != DAT_CRT ||
        !(dat_file.crt.flags & CRT_FLAG_UPDATED) ||
        dat_file.crt.type != CRT_EASYFLASH ||
        !dat_file.file[0])
    {
        return false;
    }

    dat_file.crt.flags &= ~CRT_FLAG_UPDATED; // Don't ask to save file again
    return true;
}
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

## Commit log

2020-01-19 Add Fun Play/Power Play support
2020-01-24 Update pcb picture. Thanks bigby
2020-02-08 Add KCS Power Cartridge support
2020-02-08 KCS Power Cartridge support
2020-02-09 Add link to cartridge case by bigby
2020-04-05 Better error text. Thanks tulan
    [main.c]
2020-04-11 Don't enter low-power mode
2020-04-11 Don't use SysTick interrupt
2020-04-11 Correct flag clear on timer status register
    [c64_interface.c]
2020-04-14 Use timer compare to detect end of clock cycle
2020-04-26 Update with links to gerbers, BOM and firmware
2020-05-22 PCB rev. 2
    [KungFuFlash.kicad_pcb]
2020-07-08 flush stdout after printf (linux terminal seems picky about that) and some tidy up
2020-07-12 Link to rev. 2 of gerber files
2020-07-30 Add limited EAPI support
    [ld.crt.cfg]
2020-08-02 Add detection of KFF in EAPI driver
2020-11-29 Disk save (#60)
    * Basic SAVE routine by dikdom
    * D71/D81 save support
    * Autostart and device number setting
2021-02-04 Fix bug reading 64 kb file using FAT16
    [diskio.c]
2021-04-24 Fix broken Fun Play/Power Play cartridge support
2021-08-18 Check for correct fw
    [menu_sd.c]
2021-10-24 Fix broken EasyFlash VIC-II/C128 mode
    [c64_interface.c]
2022-01-02 Move launcher memory to $C000
    [ld.crt.cfg]
2022-01-02 Power-on message
2022-01-07 Fix broken mount D64 option
    [menu_sd.c]
2022-02-10 Support CRT v2.0 and WarpSpeed 128
    [menu_sd.c]
2022-05-02 Fix timing problems on some C64s
    [c64_interface.h]
2022-07-03 Load/save: Clear timer interrupt flags
2022-07-03 Device number can be set to 8-15
2023-07-24 Improve hardware error message
    [c64_interface.c, main.c]
2023-07-28 Add picture of PCB rev. 2
2025-01-04 Fix race condition in menu startup
    [main.c]
